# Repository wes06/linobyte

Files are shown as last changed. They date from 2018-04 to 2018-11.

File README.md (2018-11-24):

# LINOBYTE

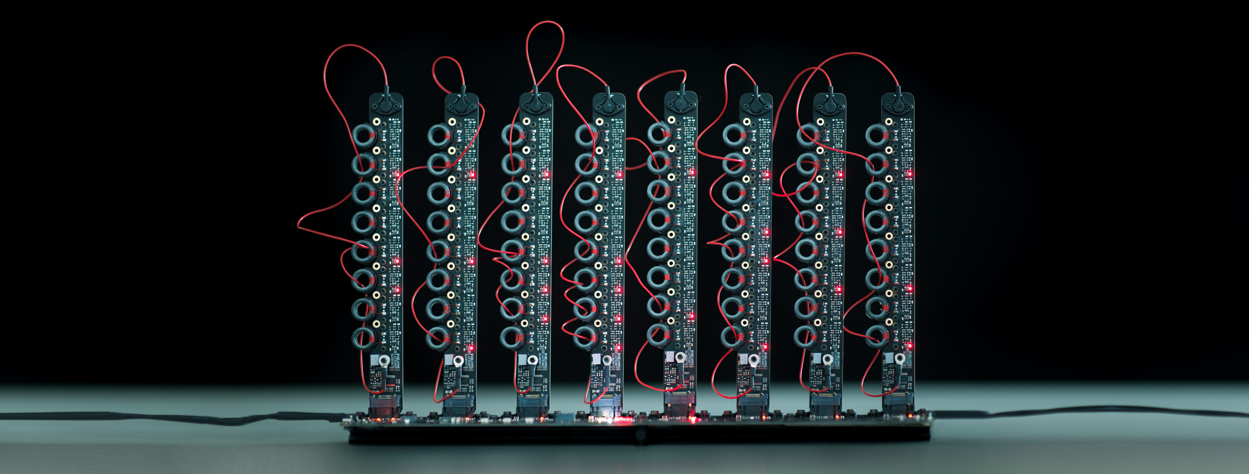
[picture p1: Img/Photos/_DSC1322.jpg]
Linobyte


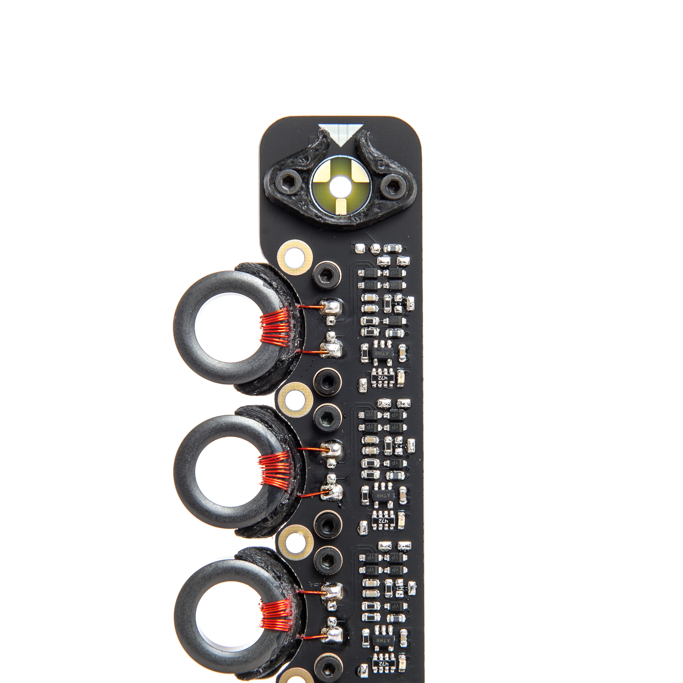
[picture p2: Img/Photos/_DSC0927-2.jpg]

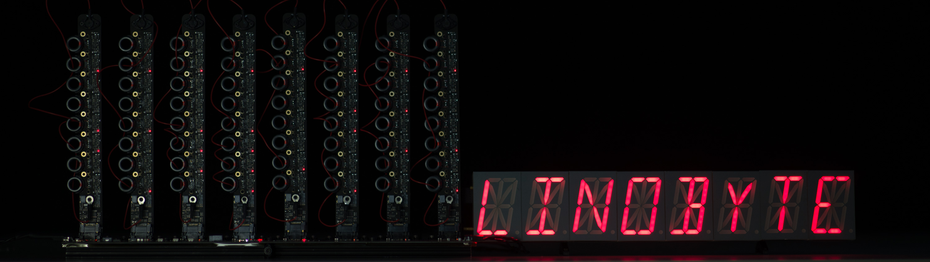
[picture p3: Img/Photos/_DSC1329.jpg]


## Table of Contents

* [Motivation and Description](#motivation-description)
* [How it works](#how-it-works)
* [Important Dates](#dates)
* [Functional Block Diagram](#block-diagram)
* [Simulations](#simulations)
* [PCBs](#pcbs)
* [Naming](#naming)
* [To Dos](#to-dos)
* [Glossary](#glossary)

## Motivation and Description

As computational devices evolve, more tools and interfaces are built between the user and the machine. This allows us to complete increasingly complex tasks without having to focus so much on understanding the nuances of the machine. While this movement is certainly overall positive, one of the drawbacks is that people no longer learn the fundamental processes and concepts which allow the tool to work. Added to that, by neglecting history, we forget the alternatives of the technologies that we use today - forgotten alternatives that maybe once were the status quo. Understanding of those alternatives would give us a broader view of the pros and cons of what we have today, how they superseded their ancestors and what are their pitfalls - important knowledge for those who design possible futures.

Its with these preocupations in mind that Linobyte came into existence. It conciliates the explanation of how bits, bytes and [chars](https://en.wikipedia.org/wiki/Character_(computing)) work, with a hands on experience of creating [Core Rope ROMs](https://en.wikipedia.org/wiki/Core_rope_memory): read-only memories that were written by weaving an enameled copper wire through ferrite cores. 

## How it works

The whole process is quite straightforward, and the result is immediate: the user can write up to 8 characters - a word, in the Linobyte system. Each character consists of one eight-bit byte. Each core represents one bit, and by weaving the conductive wire through the core center, the user sets a bit as positive. By skipping the core, its set as zero. By connecting the wire to the final position, the byte is written.  

So, if the user wants to write the "A" character, the steps should be the following:

1. Find out the binary value in ASCII of the "A" character by checking on the ASCII table (see image below). "A" in ASCII is 65 in decimal and 01000001 in binary.
2. Figure out which bits have to be set in the "Char" board: the first bit (least significant), or bit 0. And the seventh bit, bit 6. (bits are being counted from the right to left)
3. Weave a wire through the respective coils: zero and six.
4. Connect the wire to the final position (will be indicated on the board)
5. Check the character on a screen and correct or proceed to the next character.

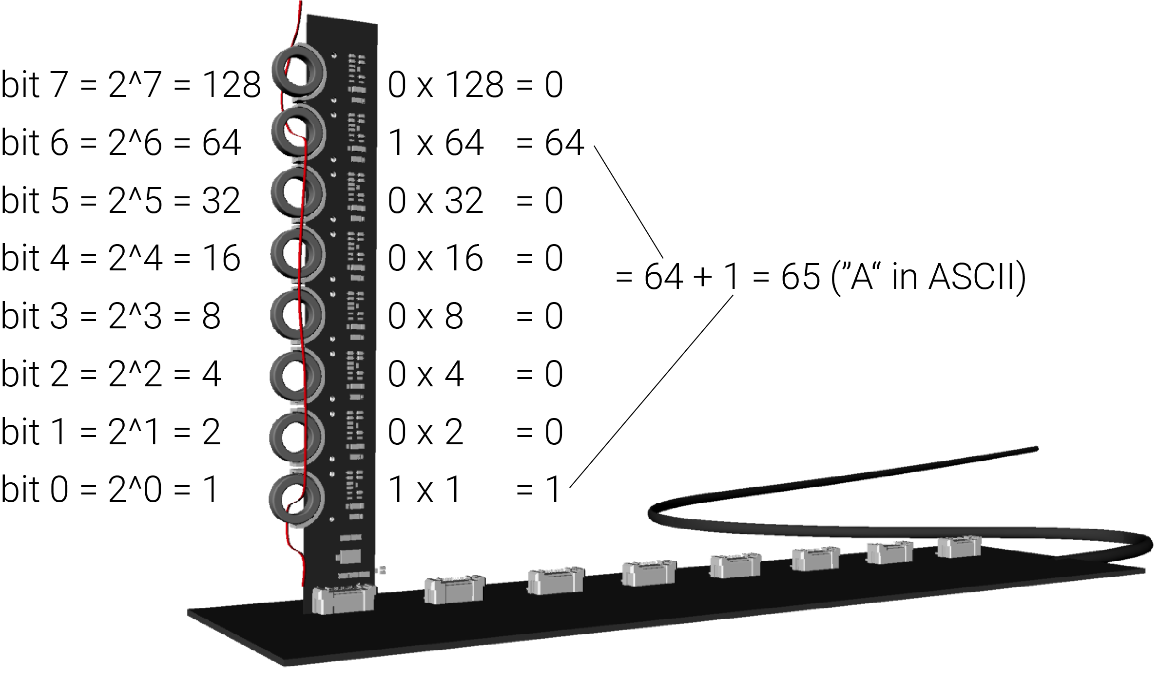
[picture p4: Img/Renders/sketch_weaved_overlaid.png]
A example
 

ASCII table:  
(I'm aware that ASCII chars only require 7 bits and not 8)



Core memory experiment from http://www.timui.org/2015/



## Functional Block Diagram

Coils are out of order in the following diagram:

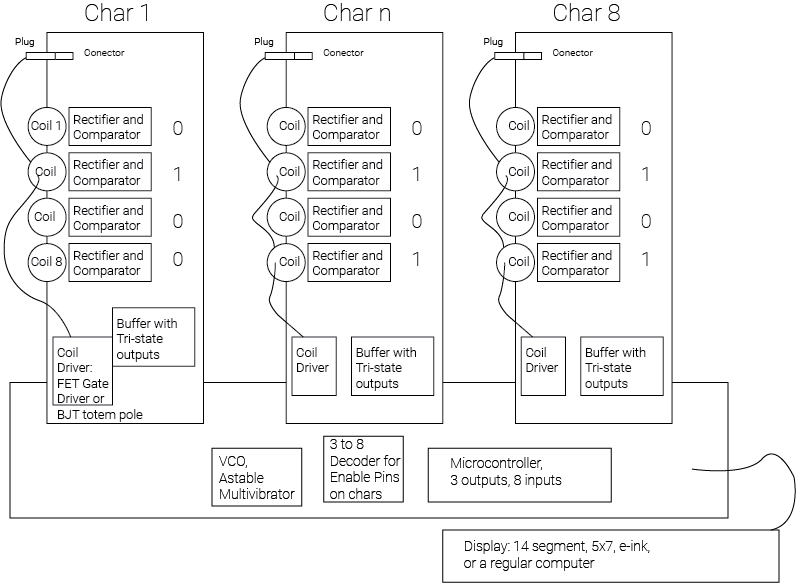
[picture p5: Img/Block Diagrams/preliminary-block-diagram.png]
Preliminary Functional Block Diagram


(So, basically, 1 word = 8 chars = 8 bytes = 8 * 8 bits)

#### Description of the main components:

##### Char

- Coil: a 1:10 to 1:30 transformer (the single turn will be the wire than can be weaved or not)
- Rectifier: Full bridge of schottky rectifiers: wire can be weaved from any direction
- Comparator: Since I don't know for sure how efficient the coil transformer will be, I want to be able to set the threshold manually.
- Coil Driver: Sends pulses through the coils. A pulse rated capacitor (probably Wima MKT) will be used in series to prevent coil saturation. Square wave signal will come from main board (either a VCO, astable multivibrator or a PWM signal from the MCU).
- Buffer with tri-state outputs: Outputs will be active or high-impedance depending on Enable pin. So I can read all chars using the same pins on the MCU.

##### Word

- VCO/Astable Multivibrator: generate a reference frequency for the coil drives. Configurable via a trimpot. Fallback will be a PWM generated by the MCU.
- 3 to 8 Decoder: with three pins on the MCU I can enable one of the 8 chars at a time, so only one of them is driving the 8 inputs on the MCU.
- Microcontroller: will read the chars and print them out.

##### Display

I personally really wanted to experiment with e-ink displays (Should be doable by adding an SPI header on the main board), but 16 segment displays or 5x7 matrixes might be more thematically suited - and are quite easy to use. Another option would be having the whole system just act as a keyboard: plug it into a computer and type the text that is in the coils (Raspberry pi + a small display for example).

##### Power supplies (not drawn)

Microcontrollers and ICs in general will use 3.3V. I might want to power the coil drivers with 5V, 12V or 24V depending on how efficient the transformers are. I plan to power the whole thing via a USB port and have the appropriate buck and boost converters on the board. I will avoid LDOs because due to the clamp diodes to 3.3V or 5V on the rectifiers, the regulator will probably need to sink some current.

## Simulations

As I designed it away from my workbench, I had to simulate some parts instead of prototyping it.

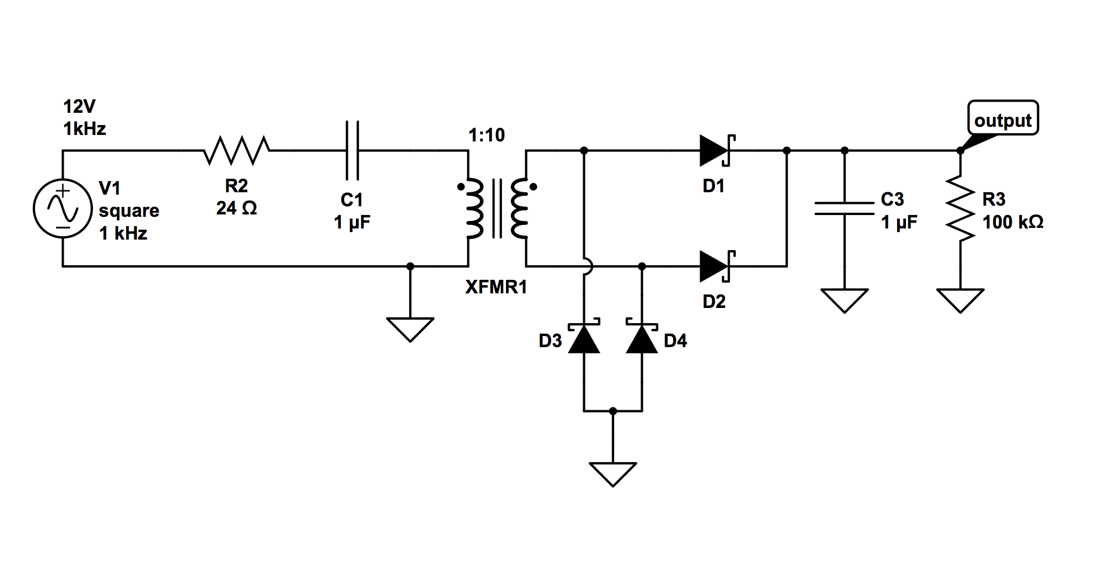
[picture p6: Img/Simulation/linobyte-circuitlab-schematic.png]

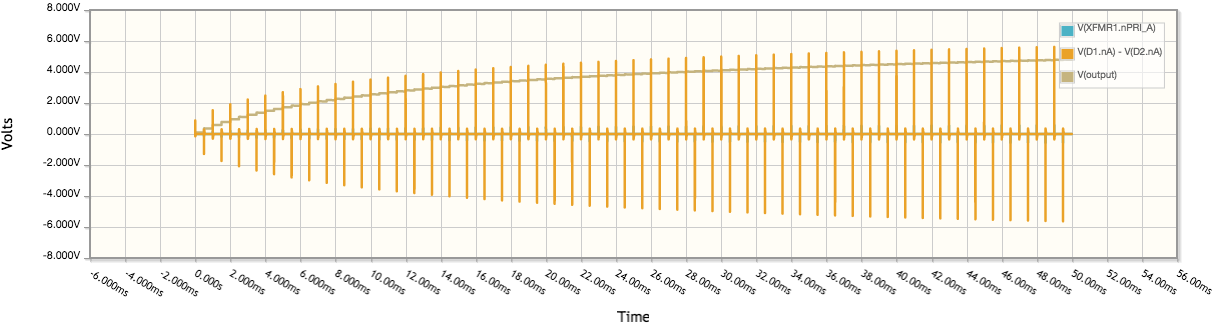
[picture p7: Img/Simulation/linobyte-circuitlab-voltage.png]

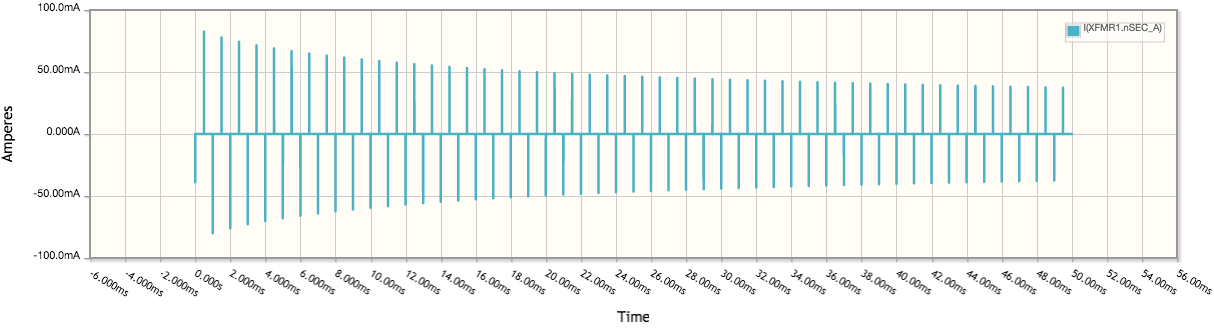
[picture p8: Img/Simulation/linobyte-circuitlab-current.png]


## PCBs

As of 19/April.  

2D view:  

  

3D view:  
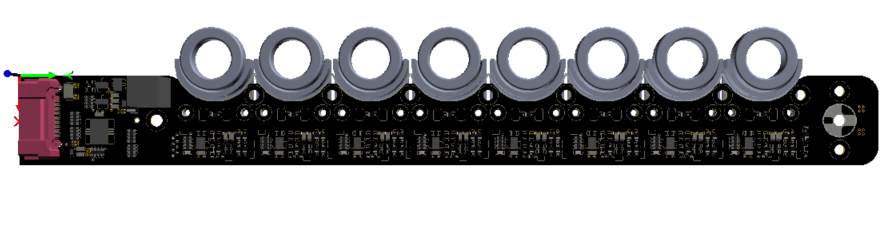
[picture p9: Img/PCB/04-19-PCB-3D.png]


As of 10/April.  

2D view:  

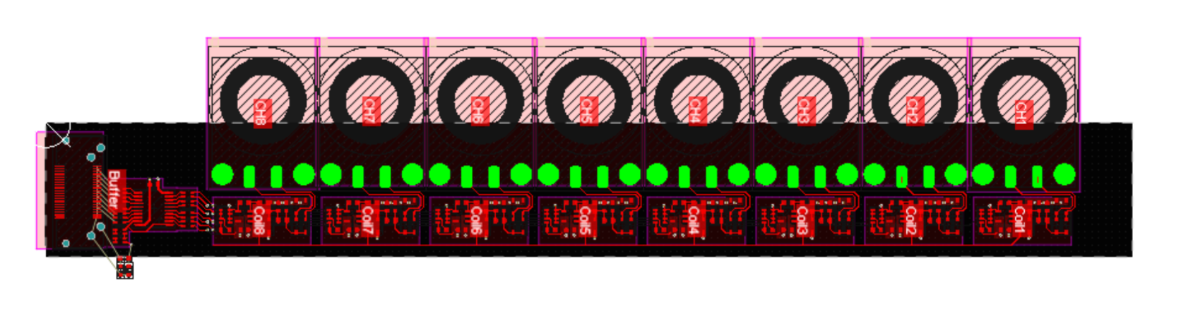
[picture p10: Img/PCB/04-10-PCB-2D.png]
  

3D view:  
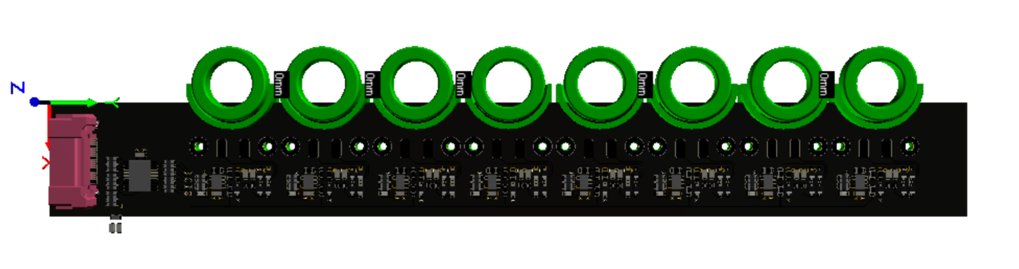
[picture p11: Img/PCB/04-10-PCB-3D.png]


## Naming

The name is a pun with the term linotype and byte:

"Linotype, typesetting machine by which characters are cast in type metal as a complete line rather than as individual characters as on the Monotype typesetting machine."

[Encyclopaedia Britannica on "Linotype"](https://www.britannica.com/technology/Linotype)  

## Refs during research

Hartmann, R. (n.d.). drhart - Core Rope Memory. [online] Drhart.ucoz.com. Available at: http://drhart.ucoz.com/index/core_memory/0-123 [Accessed Apr. 2018].

http://qrp.gr. (n.d.). Core rope memory. [online] Available at: http://qrp.gr/coreROM/ [Accessed Apr. 2018].

Ritter, T. (2002). A Magnetic Core ROM. [online] Ciphersbyritter.com. Available at: http://www.ciphersbyritter.com/MARK8/MAGCORE/MAGCORE.HTM [Accessed Apr. 2018].)

Ryals, P. (2012). Jacquard Looms and Rod ROMs. [online] Museum of Computer Culture. Available at: http://www.computerculture.org/2012/10/jacquard-looms-and-rod-roms/ [Accessed Apr. 2018].

Schlaepfer, E. (n.d.). MOnSter 6502. [online] Monster6502.com. Available at: https://monster6502.com/ [Accessed Apr. 2018].

## Examples and references during design

Pcbway.com. (n.d.). 4-layer PCB standard stackup. [online] Available at: https://www.pcbway.com/multi-layer-laminated-structure.html [Accessed May 2018].

Eeweb.com. (n.d.) Edge Coupled Microstrip Impedance Calculator. [online] Available at: https://www.eeweb.com/tools/edge-coupled-microstrip-impedance [Accessed May 2018, Tw=0.25mm Ts=0.25mm]

GitHub. (2017). dmadison/LED-Segment-ASCII. [online] Available at: https://github.com/dmadison/LED-Segment-ASCII [Accessed 10 Sep. 2018].

[Could Sawtooth waveform be optimal for transoformer input?](https://electronics.stackexchange.com/a/221279/61257)

[How to build a low cost current transformer](https://electronics.stackexchange.com/questions/116195/how-to-build-very-low-cost-current-transformer)

[AC current sensing using current transformer](https://electronics.stackexchange.com/questions/335570/ac-current-sensing-switch-using-current-transformer)

[How do I design a current transformer](https://electronics.stackexchange.com/questions/136086/how-do-i-design-a-current-transformer)

Maxim App note 3616, Adding extra histeresis to comparators  
https://www.maximintegrated.com/en/app-notes/index.mvp/id/3616

Texas Instruments: Comparator with histeresis reference design  
http://www.ti.com/lit/ug/tidu020a/tidu020a.pdf

## Potential Items for Bill of Materials

Potential coils: 9mm x 16mm x 5mm (inner, outer, thickness)  
[Mouser](https://www2.mouser.com/Passive-Components/Ferrites/Ferrite-Toroids-Ferrite-Rings/_/N-fb8t7Z1yzvvqx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|1)

Kemet ESD - R Series

[S]chmitt Trigger Octal Non Inverting](https://www.mouser.at/ProductDetail/Nexperia/74HC7541PW118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)

[3 to 8 decoder, 74HC138](https://www.mouser.at/datasheet/2/302/74HC_HCT138-1148685.pdf)

8 to 3 encoder (Auto adressing on 16 Segment Displays (shift decoded 1:8 by 1, adds 1 to 3 bit value))

Card edge 20 Pos connector  
https://www.digikey.com/product-detail/en/te-connectivity-amp-connectors/5-5530843-0/A31722-ND/770548

e-ink  
296x128 2.9in  
https://www.amazon.de/Waveshare-Resolution-Electronic-Controller-interface/dp/B071LGVVL1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

PSA23-11SRWA  (~ 300mA per char)
https://www.mouser.at/ProductDetail/Kingbright/PSA23-11SRWA?qs=VdjlWU%2fzoOGQsM3wN0NEHg==

ZXGD3005
ZXGD3009

## Glossary

- **ASCII table**: A table of correspondece between a numeric value and a character (American Standard Code for Information Interchange)

- Bit
- Byte
- Char
- **Core**: in this context, the toroid (donut) which is one of the components of the transformer that sets the bits

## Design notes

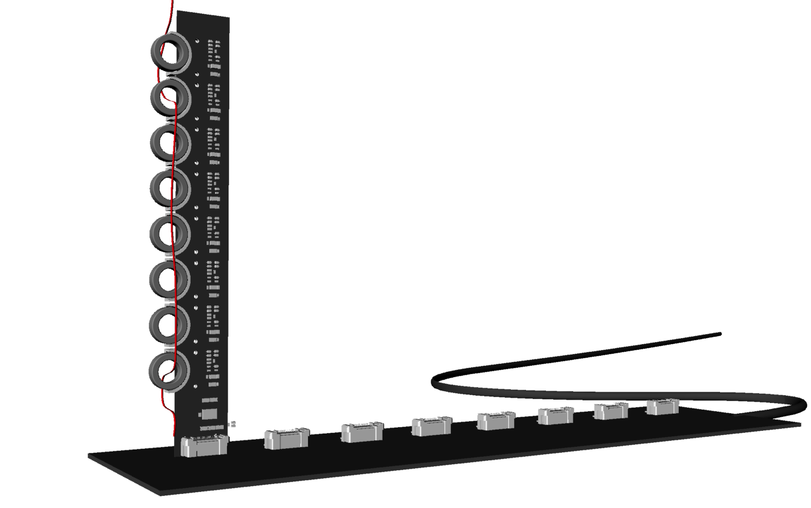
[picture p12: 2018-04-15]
Img/Renders/sketch_weaved.png

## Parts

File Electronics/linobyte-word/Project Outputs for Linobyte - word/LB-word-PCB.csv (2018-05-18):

Comment | Description | Designator | Footprint | LibRef | Quantity
100nF | Capacitor MLCC | C1, C2_Char1, C2_Char2, C2_Char3, C2_Char4, C2_Char5, C2_Char6, C2_Char7, C2_Char8, C3_Char1, C3_Char2, C3_Char3, C3_Char4, C3_Char5, C3_Char6, C3_Char7, C3_Char8, C5_Char1, C5_Char2, C5_Char3, C5_Char4, C5_Char5, C5_Char6, C5_Char7, C5_Char8, C6_Char1, C6_Char2, C6_Char3, C6_Char4, C6_Char5, C6_Char6, C6_Char7, C6_Char8, C7_Char1, C7_Char2, C7_Char3, C7_Char4, C7_Char5, C7_Char6, C7_Char7, C7_Char8, C8_Char1, C8_Char2, C8_Char3, C8_Char4, C8_Char5, C8_Char6, C8_Char7, C8_Char8, C9, C10, C11, C13, C14, C15, C16, C18, C19, C20, C21, C23, C24, C25, C26, C27, C31, C33, C34, C35, C38_Char1, C38_Char2, C38_Char3, C38_Char4, C38_Char5, C38_Char6, C38_Char7, C38_Char8, CBST1, CR1 | C0603_N | Capacitor | 79
Test Point |  | TP_COMP1, TP_LOOP1, TP_OUT1, TP_SCL, TP_SCL1, TP_SDA, TP_SDA1, TP_SHUNT1, TP_SW1, TP_VIN1, TP1_Char1, TP1_Char2, TP1_Char3, TP1_Char4, TP1_Char5, TP1_Char6, TP1_Char7, TP1_Char8, TP2_Char1, TP2_Char2, TP2_Char3, TP2_Char4, TP2_Char5, TP2_Char6, TP2_Char7, TP2_Char8, TP3, TP4, TP5, TP6, TP7, TP8, TP9, TP10, TP11, TP12, TP13, TP14, TP15, TP16, TP17, TP18, TP19, TP20, TP21, TP22, TP23, TP24, TP25 | TESTPOINT-1.2MM | Test Point | 49
LED | LED | L1, L2, L3, L4, L5, L6, L7, L8, L9, L10, L11, L12, L13, L14, L15, L16, L17, L18, L19, L20, L21, L22, L25_Char1, L25_Char2, L25_Char3, L25_Char4, L25_Char5, L25_Char6, L25_Char7, L25_Char8 | LED 0603/1608 | LED | 30
10k |  | R7_Char1, R7_Char2, R7_Char3, R7_Char4, R7_Char5, R7_Char6, R7_Char7, R7_Char8, R8_Char1, R8_Char2, R8_Char3, R8_Char4, R8_Char5, R8_Char6, R8_Char7, R8_Char8, R13, R22, R23, R24_Char1, R24_Char2, R24_Char3, R24_Char4, R24_Char5, R24_Char6, R24_Char7, R24_Char8, R27, R34 | R0603 | Resistor | 29
FB |  | FB1_Char1, FB1_Char2, FB1_Char3, FB1_Char4, FB1_Char5, FB1_Char6, FB1_Char7, FB1_Char8, FB2_Char1, FB2_Char2, FB2_Char3, FB2_Char4, FB2_Char5, FB2_Char6, FB2_Char7, FB2_Char8, FB3_Char1, FB3_Char2, FB3_Char3, FB3_Char4, FB3_Char5, FB3_Char6, FB3_Char7, FB3_Char8, FBA1 | F0603_N | Ferrite Bead | 25
SIA483DJ-T1-GE3 |  | Q1_Char1, Q1_Char2, Q1_Char3, Q1_Char4, Q1_Char5, Q1_Char6, Q1_Char7, Q1_Char8, Q2_Char1, Q2_Char2, Q2_Char3, Q2_Char4, Q2_Char5, Q2_Char6, Q2_Char7, Q2_Char8, Q4, Q5 | SC70-6L | MOSFET P CH | 18
 |  | Hole1_Char1, Hole1_Char2, Hole1_Char3, Hole1_Char4, Hole1_Char5, Hole1_Char6, Hole1_Char7, Hole1_Char8, Hole2_Char1, Hole2_Char2, Hole2_Char3, Hole2_Char4, Hole2_Char5, Hole2_Char6, Hole2_Char7, Hole2_Char8 | M3 PLATED HOLE | Hole | 16
10uF 50V | Capacitor MLCC | C4_Char1, C4_Char2, C4_Char3, C4_Char4, C4_Char5, C4_Char6, C4_Char7, C4_Char8, C28, C29, C36, C37, CI1, CI2, CI3 | C1210_N | Capacitor | 15
YC164; 1k |  | R1, R2, R3, R4, R5, R6, R11, R12, R26, R28, R29, R41 | YC164 | Resistor Array - 4P | 12
=Footprint |  | Hole3, Hole4, Hole5, Hole6, Hole7, Hole8, Hole9, Hole10, Hole11, Hole12, Hole13 | M3 PLATED HOLE | Hole | 11
Jumper 3W |  | JP1, JP3, JP11_Char1, JP11_Char2, JP11_Char3, JP11_Char4, JP11_Char5, JP11_Char6, JP11_Char7, JP11_Char8 | JUMPER SMD 3W NO | Jumper 3W | 10
74LVC1G125 | Buffer with Enable | U11_Char1, U11_Char2, U11_Char3, U11_Char4, U11_Char5, U11_Char6, U11_Char7, U11_Char8 | SC70-5 | 74LVC1G125 | 8
FX23 Vertical Plug | FX23 Vertical Plug | X1_Char1, X1_Char2, X1_Char3, X1_Char4, X1_Char5, X1_Char6, X1_Char7, X1_Char8 | FX23-40P | FX23-40P | 8
Jumper 2W |  | JP2, JP4, JP5, JP6, JP7, JP8, JP9, JP10 | JUMPER SMD 2W NO | Jumper 2W | 8
PTC | PTC, Resettable Fuse | F2_Char1, F2_Char2, F2_Char3, F2_Char4, F2_Char5, F2_Char6, F2_Char7, F2_Char8 | PTC0603 | PTC | 8
PTC1206 | PTC, Resettable Fuse | F1_Char1, F1_Char2, F1_Char3, F1_Char4, F1_Char5, F1_Char6, F1_Char7, F1_Char8 | C1206_N | PTC | 8
120R |  | R16, R20, R36, R39 | R0603 | Resistor | 4
600 |  | R35, R37, R38, R40 | R0603 | Resistor | 4
YC164; 100k |  | R15, R17, R18, R21 | YC164 | Resistor Array - 4P | 4
100pF | Capacitor MLCC | C17, C22, C32 | C0603_N | Capacitor | 3
1k |  | R9, R10, R19 | R0603 | Resistor | 3
PTC | PTC, Resettable Fuse | F3, F4, F5 | 1812 | PTC | 3
TLV171 | Single RRO Opamp | U4, U5, U6 | SOT23-5_N | TLV171 | 3
Trimpot |  | VR1, VR2, VR3 | TRIMPOT 3314 | Trimpot | 3
0R5 |  | SHUNT1, SHUNT2 | R0603 | Resistor | 2
22pF | Capacitor MLCC | CX1, CX2 | C0603_N | Capacitor | 2
22uF 10V | Capacitor MLCC | CO1, CO2 | C1210_N | Capacitor | 2
Connector 2W - TAB |  | X2, X6 | PTSM-2W-H-SMD | Connector 2W - TAB | 2
MCP23008 | I2C Port Expander | U7, U8 | QFN20 | MCP23008 | 2
RsI2C |  | RS_SCL1, RS_SDA1 | R0603 | Resistor | 2
RSX051VYM30FHTR |  | D3, D4 | SOD323F | Diode Schottky | 2
YC164; 1M |  | R42, R43 | YC164 | Resistor Array - 4P | 2
100k |  | RFB1 | R0603 | Resistor | 1
112k |  | R31 | R0603 | Resistor | 1
1778803 |  | X7 | PTSM-6W-H-SMD | Connector 6W - TAB | 1
1uF | Capacitor MLCC | C12 | C0603_N | Capacitor | 1
20021521-00010T1LF |  | SWD1 | HEADER 10P 50MIL | SWD | 1
22k |  | RFB2 | R0603 | Resistor | 1
2k5 |  | R33 | R0603 | Resistor | 1
330R |  | R14 | R0603 | Resistor | 1
50R |  | R30 | R0603 | Resistor | 1
74HC138 | 3 to 8 Decoder | U1 | DHVQFN16 | 74HC138 | 1
74HC7541 | Schmitt Trigger Octal | U2 | TSSOP20_N | 74HC7541 | 1
78k7 |  | R32 | R0603 | Resistor | 1
824521121 |  | D7 | SOD323F | TVS | 1
824521121 |  | TVS1 | DO214AC SMA | TVS Bidirectional | 1
ATSAMD21G18 |  | U3 | QFN48_M | ATSAMD21G18 | 1
CFF | Capacitor MLCC | CFF1 | C0603_N | Capacitor | 1
Connector 10W - TAB |  | X5 | FPC CONN. 10W 1-84953-0 | Connector 10W - TAB | 1
Ferrite Bead |  | FB4 | F0603_N | Ferrite Bead | 1
Header 14Pos 7x2 |  | X4 | HEADER 7X2 SMD 2.54MM | Header 14Pos 7x2 | 1
Inductor |  | L24 | INDUCTOR SRP1040 | Inductor | 1
LFXTAL050789 |  | X3 | CRYSTAL 0805 | Crystal | 1
MM3Z3V3ST1G |  | D1 |  | TVS | 1
MM3Z3V3ST1G |  | D5 | SOD323F-COMCHIP VARIANT | TVS | 1
MOSFET N CH |  | Q3 | SOT23_N | MOSFET N CH | 1
PCA9615 |  | U10 | TSSOP10 | PCA9615DP | 1
SBR5E60P5-13D |  | D6 | POWERDI5 | Diode Schottky | 1
SRP7028 |  | L23 | INDUCTOR SRP7028 | Inductor | 1
T55D336M035C0100 | Polarized Cap | C30 | 2917 - CASE D | Capacitor Polarized | 1
TPD3E001 |  | TVS2 | SOT23-5_N | TPD3E001 | 1
TPS54308 | Buck Converter | IC1 | SOT23 | TPS54308 | 1
TPS55340 | Boost/SEPIC/Flyback converter | U9 | QFN16 | TPS55340 | 1
USB Micro |  | USB1 | USB MICRO | USB Micro | 1
YC164; 10k |  | R25 | YC164 | Resistor Array - 4P | 1
YC164; 4k7 |  | RI1 | YC164 | Resistor Array - 4P | 1

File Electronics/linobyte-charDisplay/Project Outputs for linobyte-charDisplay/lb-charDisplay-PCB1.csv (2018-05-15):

Comment | Value | Description | Designator | Footprint | LibRef | Quantity
 |  |  | RFB1A | R0603 | Resistor | 1
0R5 | 0R5 |  | SHUNT1 | R0603 | Resistor | 1
10uF 50V | 10uF 50V | Capacitor MLCC | CI1 | C1210_N | Capacitor | 1
16 Segment Display |  |  | DISP1 | PSA23-11SRWA | Display 16 Segment | 1
22k | 22k |  | RFB2 | R0603 | Resistor | 1
22uF 10V | 22uF 10V | Capacitor MLCC | CO1 | C1210_N | Capacitor | 1
100k | 100k |  | RFB1B | R0603 | Resistor | 1
100nF | 100nF | Capacitor MLCC | C1, C2, C3, C4, C5, C6, C7, C8, CBST1 | C0603_N | Capacitor | 9
120 | 120 |  | R4, R7 | R0603 | Resistor | 2
600 | 600 |  | R3, R5, R6, R8 | R0603 | Resistor | 4
1778803 |  |  | X3 | PTSM-6W-H-SMD | Connector 6W - TAB | 1
; 4k7 | 4k7 |  | R1, R2 | YC164 | Resistor Array - 4P | 2
=Footprint |  |  | Hole1, Hole2, Hole3, Hole4 | Insert-Thread-SMD-M2 | Hole | 4
Connector 10W - TAB |  |  | X1, X2 | FPC Conn. 10W 1-84953-0 | Connector 10W - TAB | 2
HVQFN28 |  |  | U3 | QFN28 | PCA9685 | 1
Inductor | 15uH |  | L1 | Inductor 4mm | Inductor | 1
Jumper 2W |  |  | JP_A0, JP_A1, JP_A2, JP_A3, JP_A4, JP_A5, JP1, JP2, JP3 | Jumper SMD 2W NO | Jumper 2W | 9
Jumper 3W |  |  | JP4, JP5 | Jumper SMD 3W NO | Jumper 3W | 2
PCA9615 |  |  | U1 | TSSOP10 | PCA9615DP | 1
Resistor Array - 4P |  |  | R17, R18, R20, R21 | YC164 | Resistor Array - 4P | 4
Test Point |  |  | TP1, TP2, TP3, TP4, TP5, TP6 | TestPoint-1.2mm | Test Point | 6
TPS54308 |  | Buck Converter | IC1 | SOT23 | TPS54308 | 1
TPS70933 |  |  | U2 | SOT23-5_N | XC6222 | 1

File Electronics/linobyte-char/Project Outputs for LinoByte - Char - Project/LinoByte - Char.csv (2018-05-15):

Comment | Description | Designator | Footprint | LibRef | Quantity
Silkscreen Digit |  | 1_CH1, 1_CH2, 1_CH3, 1_CH4, 1_CH5, 1_CH6, 1_CH7, 1_CH8 | PCB-7SEG-10MM | PCB-7Seg | 8
100nF | Capacitor MLCC | C1_Coil1, C1_Coil2, C1_Coil3, C1_Coil4, C1_Coil5, C1_Coil6, C1_Coil7, C1_Coil8, C2_Coil1, C2_Coil2, C2_Coil3, C2_Coil4, C2_Coil5, C2_Coil6, C2_Coil7, C2_Coil8, C3, C4, C4_Coil1, C4_Coil2, C4_Coil3, C4_Coil4, C4_Coil5, C4_Coil6, C4_Coil7, C4_Coil8, C5, C7, C10 | C0603_N | Capacitor | 29
Film |  | C6 | CAP FILM 5MM PITCH, 7.2X7.2MM | Capacitor - Film | 1
1206 10uF 25V | Capacitor MLCC | C8 | C1206_N | Capacitor | 1
1uF | Capacitor MLCC | C9 | C0603_N | Capacitor | 1
DNP | Capacitor MLCC | C11 | C0603_N | Capacitor | 1
RSX051VYM30FHTR |  | D1, D2, D4, DClamp_Coil1, DClamp_Coil2, DClamp_Coil3, DClamp_Coil4, DClamp_Coil5, DClamp_Coil6, DClamp_Coil7, DClamp_Coil8, DR1_Coil1, DR1_Coil2, DR1_Coil3, DR1_Coil4, DR1_Coil5, DR1_Coil6, DR1_Coil7, DR1_Coil8, DR2_Coil1, DR2_Coil2, DR2_Coil3, DR2_Coil4, DR2_Coil5, DR2_Coil6, DR2_Coil7, DR2_Coil8, DR3_Coil1, DR3_Coil2, DR3_Coil3, DR3_Coil4, DR3_Coil5, DR3_Coil6, DR3_Coil7, DR3_Coil8, DR4_Coil1, DR4_Coil2, DR4_Coil3, DR4_Coil4, DR4_Coil5, DR4_Coil6, DR4_Coil7, DR4_Coil8 | SOD323F | Diode, Diode Schottky | 43
TVS |  | D3 |  | TVS | 1
FB |  | FB1_Coil1, FB1_Coil2, FB1_Coil3, FB1_Coil4, FB1_Coil5, FB1_Coil6, FB1_Coil7, FB1_Coil8 | R0603 | Resistor | 8
Ferrite Bead |  | FB2 | F0603_N | Ferrite Bead | 1
FB |  | FB3 | F0603_N | Ferrite Bead | 1
Hole |  | Hole1 | INSERT-THREAD-SMD-M2 | Hole | 1
linobyte-coil |  | L1_CH1, L1_CH2, L1_CH3, L1_CH4, L1_CH5, L1_CH6, L1_CH7, L1_CH8 | LINOBYTE-COIL | linobyte-coil | 8
LED | LED | L1_Coil1, L1_Coil2, L1_Coil3, L1_Coil4, L1_Coil5, L1_Coil6, L1_Coil7, L1_Coil8 | LED 0603/1608 | LED | 8
MOSFET N CH |  | Q1, Q2 | SOT23_N | MOSFET N CH | 2
120R |  | R1_Coil1, R1_Coil2, R1_Coil3, R1_Coil4, R1_Coil5, R1_Coil6, R1_Coil7, R1_Coil8, R12 | R0603 | Resistor | 9
; 1k |  | R2, R4, R5, R6, R7 | YC164 | Resistor Array - 4P | 5
1M |  | R3_Coil1, R3_Coil2, R3_Coil3, R3_Coil4, R3_Coil5, R3_Coil6, R3_Coil7, R3_Coil8 | R0603 | Resistor | 8
DNP |  | R4_Coil1, R4_Coil2, R4_Coil3, R4_Coil4, R4_Coil5, R4_Coil6, R4_Coil7, R4_Coil8 | R0603 | Resistor | 8
YC164; 1k |  | R8_Coil1, R8_Coil2, R8_Coil3, R8_Coil4, R8_Coil5, R8_Coil6, R8_Coil7, R8_Coil8, R9 | YC164 | Resistor Array - 4P | 9
1k |  | R10, R11, Rin_Coil1, Rin_Coil2, Rin_Coil3, Rin_Coil4, Rin_Coil5, Rin_Coil6, Rin_Coil7, Rin_Coil8 | R0603 | Resistor | 10
4k7 |  | Rfb_Coil1, Rfb_Coil2, Rfb_Coil3, Rfb_Coil4, Rfb_Coil5, Rfb_Coil6, Rfb_Coil7, Rfb_Coil8 | R0603 | Resistor | 8
Switch for the magnet |  | SW1 | LINOBYTE - MAGNETSWITCH | Linobyte - MagnetSwitch | 1
Test Point |  | TP1_Coil1, TP1_Coil2, TP1_Coil3, TP1_Coil4, TP1_Coil5, TP1_Coil6, TP1_Coil7, TP1_Coil8, TP2_Coil1, TP2_Coil2, TP2_Coil3, TP2_Coil4, TP2_Coil5, TP2_Coil6, TP2_Coil7, TP2_Coil8, TP3_Coil1, TP3_Coil2, TP3_Coil3, TP3_Coil4, TP3_Coil5, TP3_Coil6, TP3_Coil7, TP3_Coil8, TP4_Coil1, TP4_Coil2, TP4_Coil3, TP4_Coil4, TP4_Coil5, TP4_Coil6, TP4_Coil7, TP4_Coil8 | HARWIN S2751-46R | Test Point | 32
TVS Bidirectional |  | TVS1 | DO214AC SMA | TVS Bidirectional | 1
TVS Bidirectional |  | TVS2_Coil1, TVS2_Coil2, TVS2_Coil3, TVS2_Coil4, TVS2_Coil5, TVS2_Coil6, TVS2_Coil7, TVS2_Coil8 |  | TVS Bidirectional | 8
74HC7541 | Schmitt Trigger Octal | U1 | TSSOP20_N | 74HC7541 | 1
ZXGD3005 |  | U2 | SOT23-6_N | ZXGD3005 | 1
MCP6541U |  | U3_Coil1, U3_Coil2, U3_Coil3, U3_Coil4, U3_Coil5, U3_Coil6, U3_Coil7, U3_Coil8 | SOT23-5_N | MCP6541U | 8
FX23 Right Angle Receptacle | FX23 Right Angle Receptacle 40 Pos | X1 | FX23-40S-0.5SH | FX23-40S-0.5SH | 1

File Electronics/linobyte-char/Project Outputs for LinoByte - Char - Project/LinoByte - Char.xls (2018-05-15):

Comment | Description | Designator | Footprint | LibRef | Quantity
Silkscreen Digit |  | 1_CH1, 1_CH2, 1_CH3, 1_CH4, 1_CH5, 1_CH6, 1_CH7, 1_CH8 | PCB-7SEG-10MM | PCB-7Seg | 8.0
100nF | Capacitor MLCC | C1_Coil1, C1_Coil2, C1_Coil3, C1_Coil4, C1_Coil5, C1_Coil6, C1_Coil7, C1_Coil8, C2_Coil1, C2_Coil2, C2_Coil3, C2_Coil4, C2_Coil5, C2_Coil6, C2_Coil7, C2_Coil8, C3, C4, C4_Coil1, C4_Coil2, C4_Coil3, C4_Coil4, C4_Coil5, C4_Coil6, C4_Coil7, C4_Coil8, C5, C7, C10 | C0603_N | Capacitor | 29.0
Film |  | C6 | CAP FILM 5MM PITCH, 7.2X7.2MM | Capacitor - Film | 1.0
1206 10uF 25V | Capacitor MLCC | C8 | C1206_N | Capacitor | 1.0
1uF | Capacitor MLCC | C9 | C0603_N | Capacitor | 1.0
DNP | Capacitor MLCC | C11 | C0603_N | Capacitor | 1.0
RSX051VYM30FHTR |  | D1, D2, D4, DClamp_Coil1, DClamp_Coil2, DClamp_Coil3, DClamp_Coil4, DClamp_Coil5, DClamp_Coil6, DClamp_Coil7, DClamp_Coil8, DR1_Coil1, DR1_Coil2, DR1_Coil3, DR1_Coil4, DR1_Coil5, DR1_Coil6, DR1_Coil7, DR1_Coil8, DR2_Coil1, DR2_Coil2, DR2_Coil3, DR2_Coil4, DR2_Coil5, DR2_Coil6, DR2_Coil7, DR2_Coil8, DR3_Coil1, DR3_Coil2, DR3_Coil3, DR3_Coil4, DR3_Coil5, DR3_Coil6, DR3_Coil7, DR3_Coil8, DR4_Coil1, DR4_Coil2, DR4_Coil3, DR4_Coil4, DR4_Coil5, DR4_Coil6, DR4_Coil7, DR4_Coil8 | SOD323F | Diode, Diode Schottky | 43.0
TVS |  | D3 |  | TVS | 1.0
FB |  | FB1_Coil1, FB1_Coil2, FB1_Coil3, FB1_Coil4, FB1_Coil5, FB1_Coil6, FB1_Coil7, FB1_Coil8 | R0603 | Resistor | 8.0
Ferrite Bead |  | FB2 | F0603_N | Ferrite Bead | 1.0
FB |  | FB3 | F0603_N | Ferrite Bead | 1.0
Hole |  | Hole1 | INSERT-THREAD-SMD-M2 | Hole | 1.0
linobyte-coil |  | L1_CH1, L1_CH2, L1_CH3, L1_CH4, L1_CH5, L1_CH6, L1_CH7, L1_CH8 | LINOBYTE-COIL | linobyte-coil | 8.0
LED | LED | L1_Coil1, L1_Coil2, L1_Coil3, L1_Coil4, L1_Coil5, L1_Coil6, L1_Coil7, L1_Coil8 | LED 0603/1608 | LED | 8.0
MOSFET N CH |  | Q1, Q2 | SOT23_N | MOSFET N CH | 2.0
120R |  | R1_Coil1, R1_Coil2, R1_Coil3, R1_Coil4, R1_Coil5, R1_Coil6, R1_Coil7, R1_Coil8, R12 | R0603 | Resistor | 9.0
; 1k |  | R2, R4, R5, R6, R7 | YC164 | Resistor Array - 4P | 5.0
1M |  | R3_Coil1, R3_Coil2, R3_Coil3, R3_Coil4, R3_Coil5, R3_Coil6, R3_Coil7, R3_Coil8 | R0603 | Resistor | 8.0
DNP |  | R4_Coil1, R4_Coil2, R4_Coil3, R4_Coil4, R4_Coil5, R4_Coil6, R4_Coil7, R4_Coil8 | R0603 | Resistor | 8.0
YC164; 1k |  | R8_Coil1, R8_Coil2, R8_Coil3, R8_Coil4, R8_Coil5, R8_Coil6, R8_Coil7, R8_Coil8, R9 | YC164 | Resistor Array - 4P | 9.0
1k |  | R10, R11, Rin_Coil1, Rin_Coil2, Rin_Coil3, Rin_Coil4, Rin_Coil5, Rin_Coil6, Rin_Coil7, Rin_Coil8 | R0603 | Resistor | 10.0
4k7 |  | Rfb_Coil1, Rfb_Coil2, Rfb_Coil3, Rfb_Coil4, Rfb_Coil5, Rfb_Coil6, Rfb_Coil7, Rfb_Coil8 | R0603 | Resistor | 8.0
Switch for the magnet |  | SW1 | LINOBYTE - MAGNETSWITCH | Linobyte - MagnetSwitch | 1.0
Test Point |  | TP1_Coil1, TP1_Coil2, TP1_Coil3, TP1_Coil4, TP1_Coil5, TP1_Coil6, TP1_Coil7, TP1_Coil8, TP2_Coil1, TP2_Coil2, TP2_Coil3, TP2_Coil4, TP2_Coil5, TP2_Coil6, TP2_Coil7, TP2_Coil8, TP3_Coil1, TP3_Coil2, TP3_Coil3, TP3_Coil4, TP3_Coil5, TP3_Coil6, TP3_Coil7, TP3_Coil8, TP4_Coil1, TP4_Coil2, TP4_Coil3, TP4_Coil4, TP4_Coil5, TP4_Coil6, TP4_Coil7, TP4_Coil8 | HARWIN S2751-46R | Test Point | 32.0
TVS Bidirectional |  | TVS1 | DO214AC SMA | TVS Bidirectional | 1.0
TVS Bidirectional |  | TVS2_Coil1, TVS2_Coil2, TVS2_Coil3, TVS2_Coil4, TVS2_Coil5, TVS2_Coil6, TVS2_Coil7, TVS2_Coil8 |  | TVS Bidirectional | 8.0
74HC7541 | Schmitt Trigger Octal | U1 | TSSOP20_N | 74HC7541 | 1.0
ZXGD3005 |  | U2 | SOT23-6_N | ZXGD3005 | 1.0
MCP6541U |  | U3_Coil1, U3_Coil2, U3_Coil3, U3_Coil4, U3_Coil5, U3_Coil6, U3_Coil7, U3_Coil8 | SOT23-5_N | MCP6541U | 8.0
FX23 Right Angle Receptacle | FX23 Right Angle Receptacle 40 Pos | X1 | FX23-40S-0.5SH | FX23-40S-0.5SH | 1.0

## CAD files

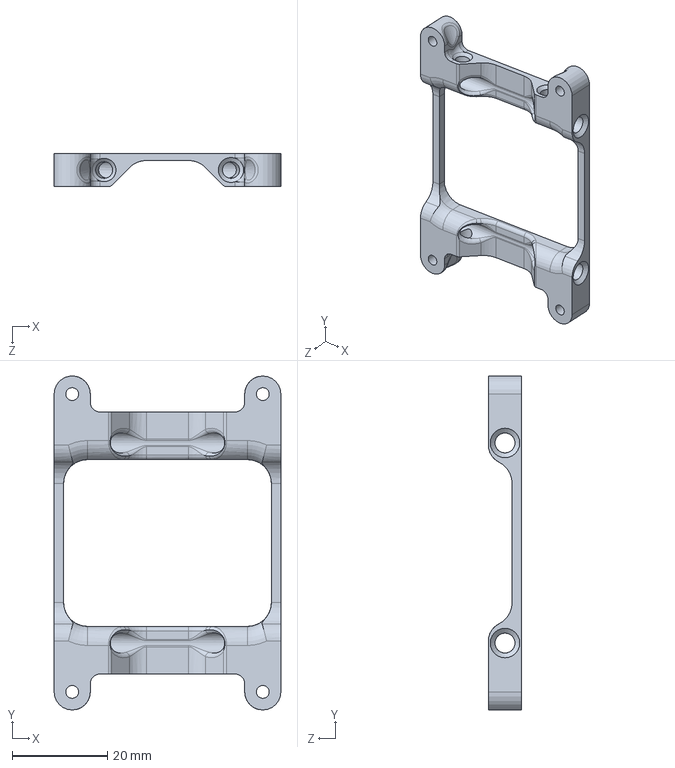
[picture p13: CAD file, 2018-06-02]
Mechanical/Char Display/LB-charDisp-Support.SLDPRT
47.6 x 70.1 x 7.00 mm

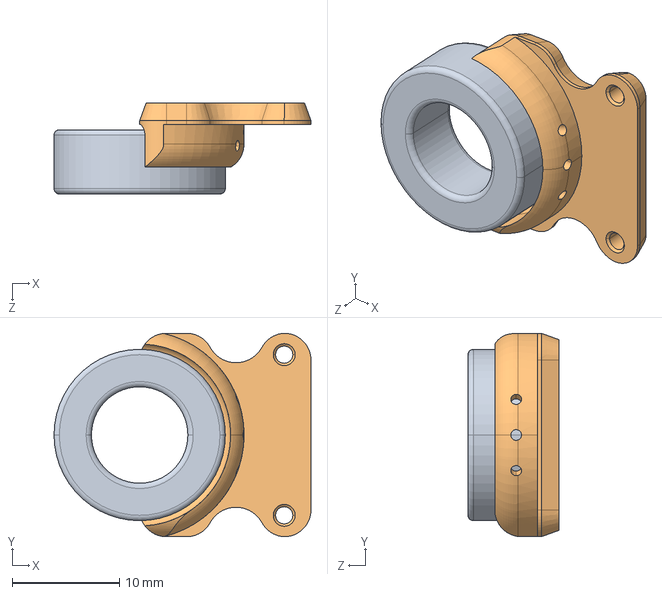
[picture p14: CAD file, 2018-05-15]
Mechanical/Chars/Coil Holders/Linobyte-CoilHolderSketch.STEP
24.0 x 19.0 x 8.50 mm

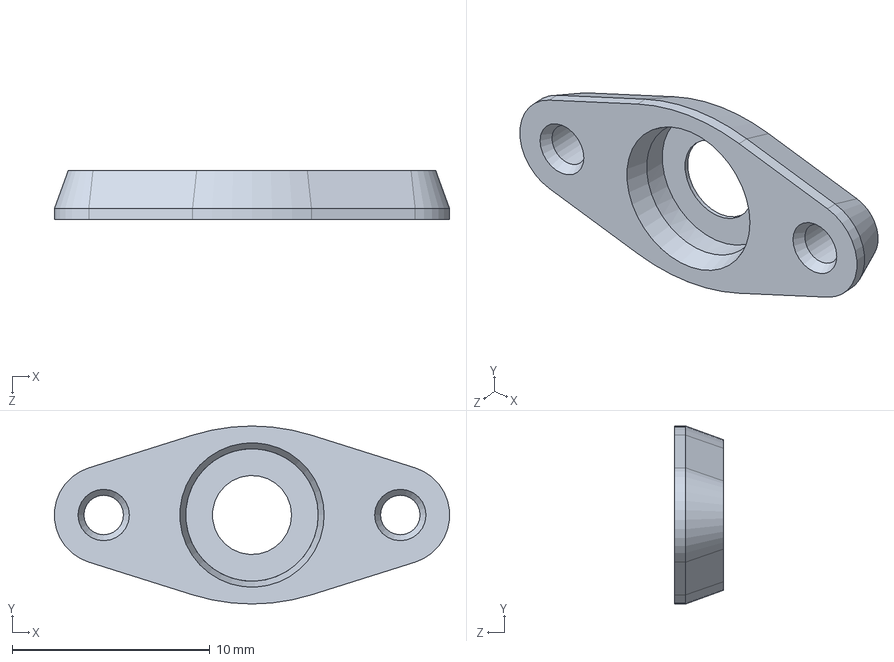
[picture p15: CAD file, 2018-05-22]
Mechanical/Chars/MagnetHolder/LB-magnetHolder-Back.SLDPRT
20.0 x 9.00 x 2.50 mm

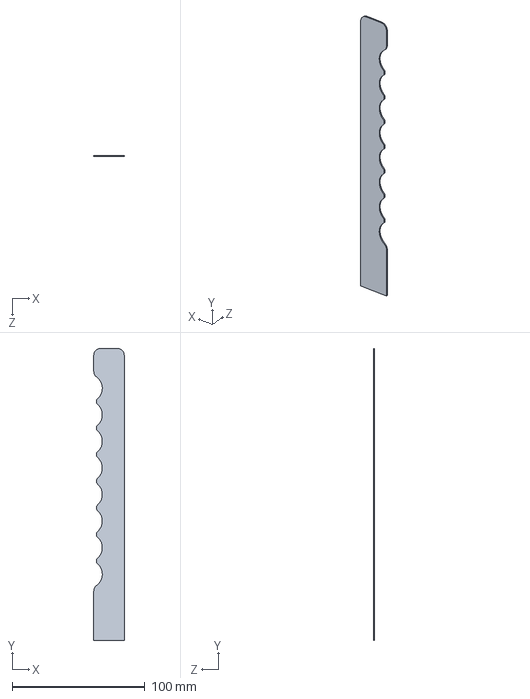
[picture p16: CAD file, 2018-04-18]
Mechanical/Chars/PCB-Shape/Linobyte - PCB Shape.SLDPRT
23.0 x 220.0 x 1.00 mm

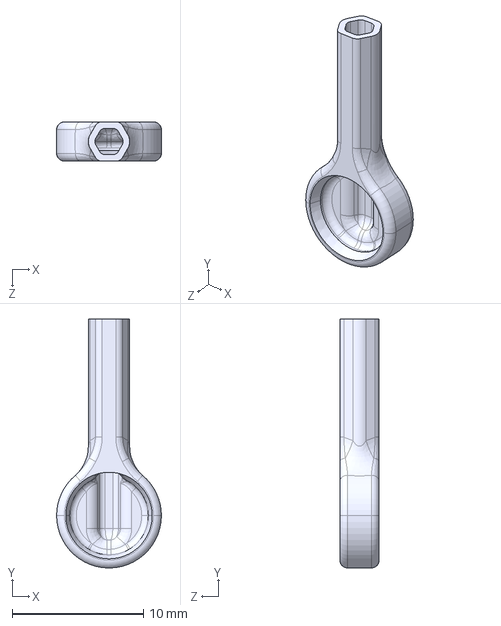
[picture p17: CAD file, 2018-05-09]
Mechanical/Chars/WireMagnetClamp/WireMagnetClamp.STEP
8.00 x 19.0 x 3.00 mm

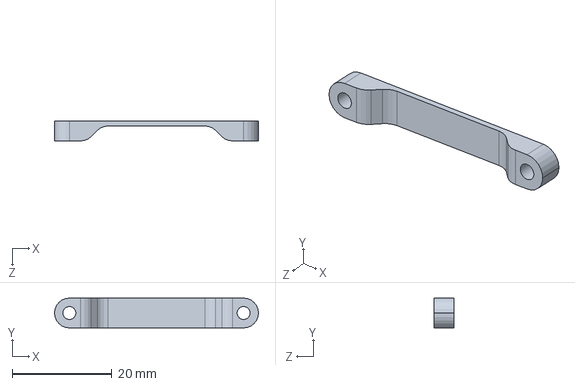
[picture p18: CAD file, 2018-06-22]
Mechanical/Word/LB-Word-charGuide-bottom.SLDPRT
41.0 x 6.00 x 4.00 mm

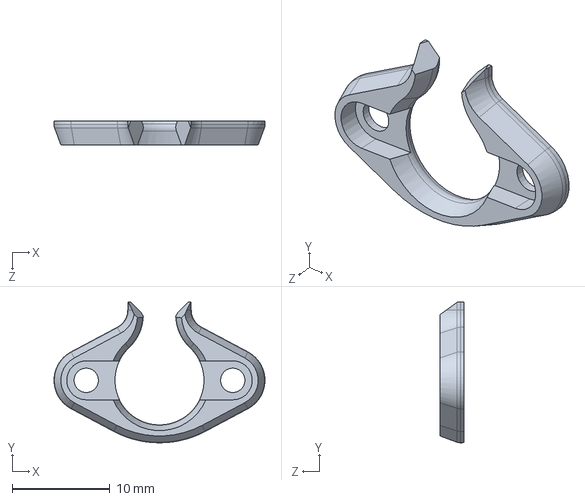
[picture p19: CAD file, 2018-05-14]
Mechanical/Chars/MagnetHolder/LB-magnetHolder-Front-RevA.SLDPRT
21.6 x 14.4 x 2.50 mm

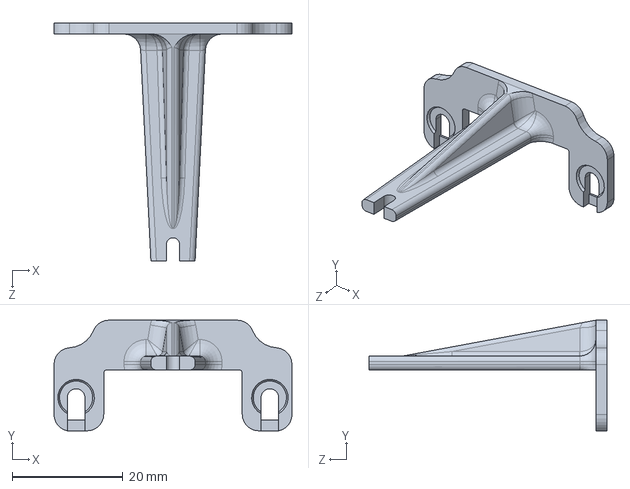
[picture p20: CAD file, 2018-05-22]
Mechanical/Word/LB-Word-charGuide.SLDPRT
43.0 x 20.0 x 43.0 mm

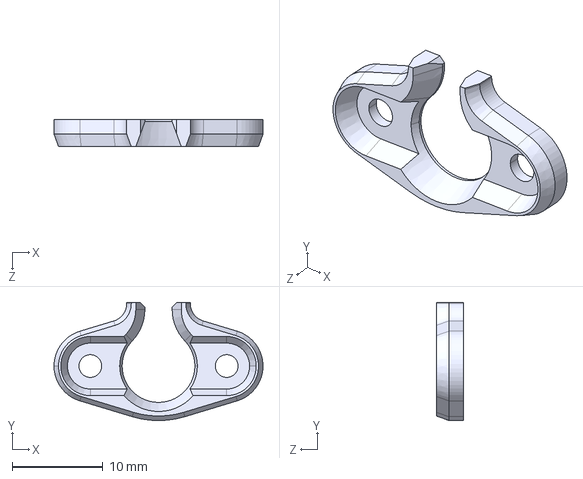
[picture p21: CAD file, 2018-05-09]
Mechanical/Chars/MagnetHolder/LB-magnetHolder-Front.STEP
23.0 x 13.0 x 3.00 mm

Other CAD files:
Mechanical/Char Display/LB-charDisp-Support.STL
Mechanical/Chars/Coil Holders/Linobyte-CoilHolderSketch.SLDPRT
Mechanical/Chars/Coil Holders/Linobyte-CoilHolderSketch.STL
Mechanical/Chars/MagnetHolder/LB-magnetHolder-Back.STL
Mechanical/Chars/MagnetHolder/LB-magnetHolder-Front-RevA.STL
Mechanical/Chars/MagnetHolder/LB-magnetHolder-Front.SLDPRT
Mechanical/Chars/MagnetHolder/LB-magnetHolder-Front.STL
Mechanical/Chars/PCB-Shape/Linobyte - PCB Shape.DWG
Mechanical/Chars/WireMagnetClamp/WireMagnetClamp.SLDPRT
Mechanical/Chars/WireMagnetClamp/WireMagnetClamp.STL
Mechanical/Word/LB-Word-charGuide-bottom.STL
Mechanical/Word/LB-Word-charGuide.STL

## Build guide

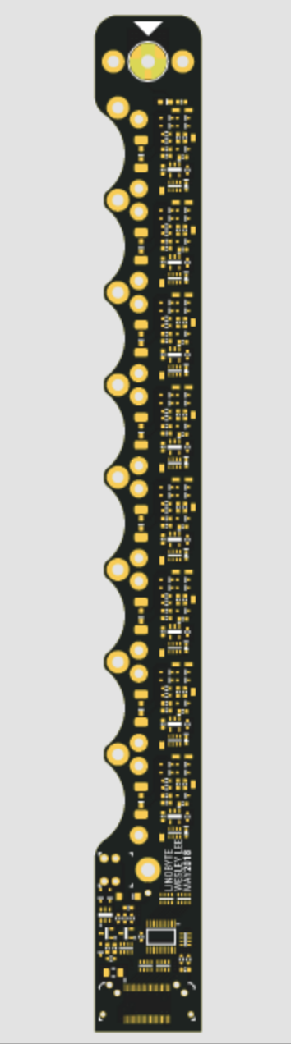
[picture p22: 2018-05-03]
Electronics/linobyte-char/Project Outputs for LinoByte - Char - Project/Fabrication/reference.png

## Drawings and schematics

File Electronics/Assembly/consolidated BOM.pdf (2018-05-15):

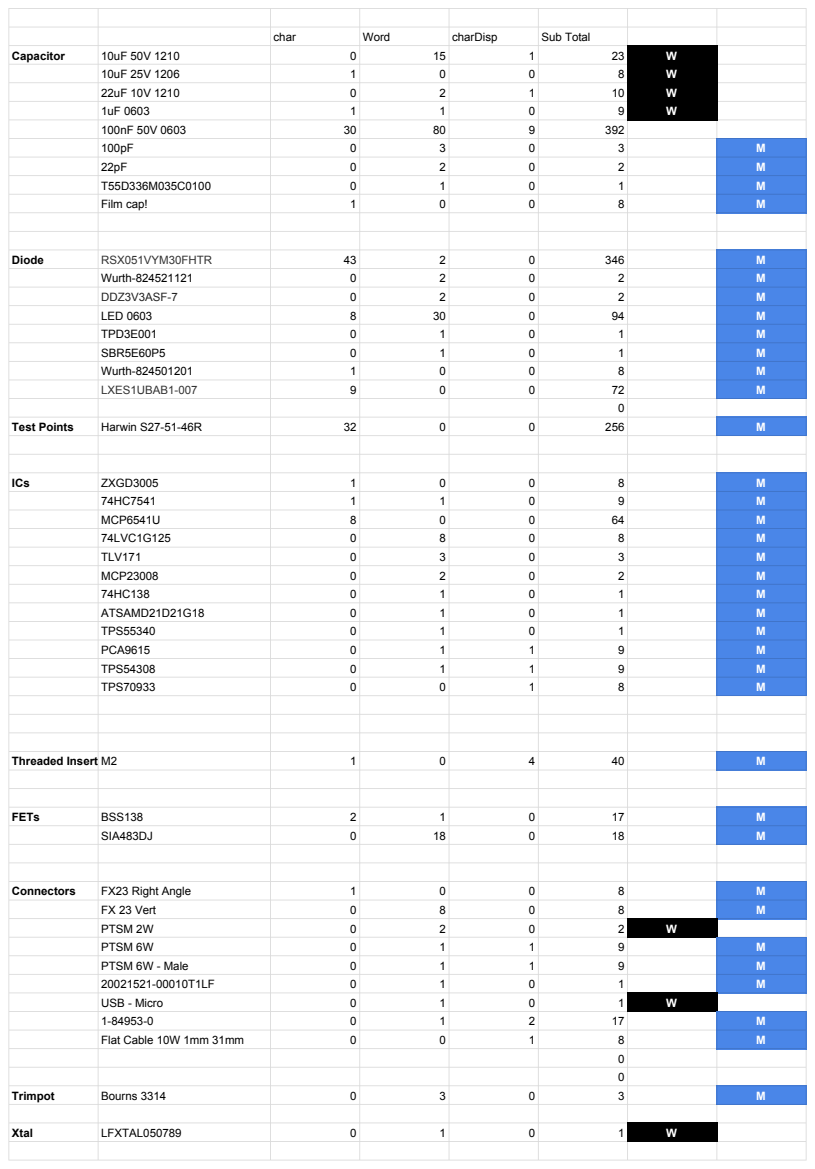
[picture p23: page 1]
char; Word; charDisp; Sub Total; Capacitor; Film cap!; Diode; RSX051VYM30FHTR; Wurth-824521121; Test Points; Harwin S27-51-46R; ICs; ZXGD3005; MCP6541U; 74LVC1G125; TLV171; MCP23008; ATSAMD21D21G18; TPS55340; PCA9615; TPS54308; TPS70933; Threaded Insert M2; FETs; BSS138; SIA483DJ; Connectors; FX23 Right Angle; FX 23 Vert; PTSM 2W; PTSM 6W; PTSM 6W - Male; USB - Micro; Flat Cable 10W 1mm 31mm; Trimpot; Bourns 3314; Xtal; LFXTAL050789

DDZ3V3ASF-7 | 0 2 | M
LED 0603 8 30 0 94 TPD3E001 0 1 0 1 SBR5E60P5 0 1 0 1 Wurth-824501201 1 0 0 8 | | M M

LXES1UBAB1-007 | 9 0 0 72 | M

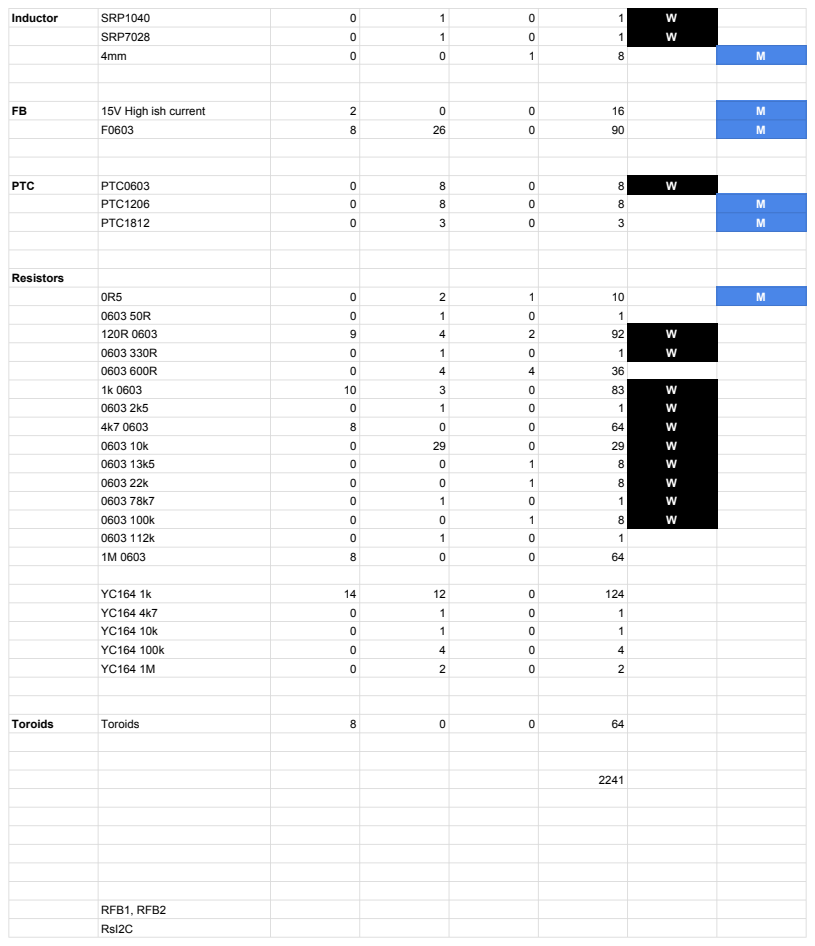
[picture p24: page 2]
Inductor; SRP1040; SRP7028; 15V High ish current; PTC; PTC0603; PTC1206; PTC1812; Resistors; Toroids; RFB1, RFB2; RsI2C

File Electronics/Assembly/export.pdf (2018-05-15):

# Char

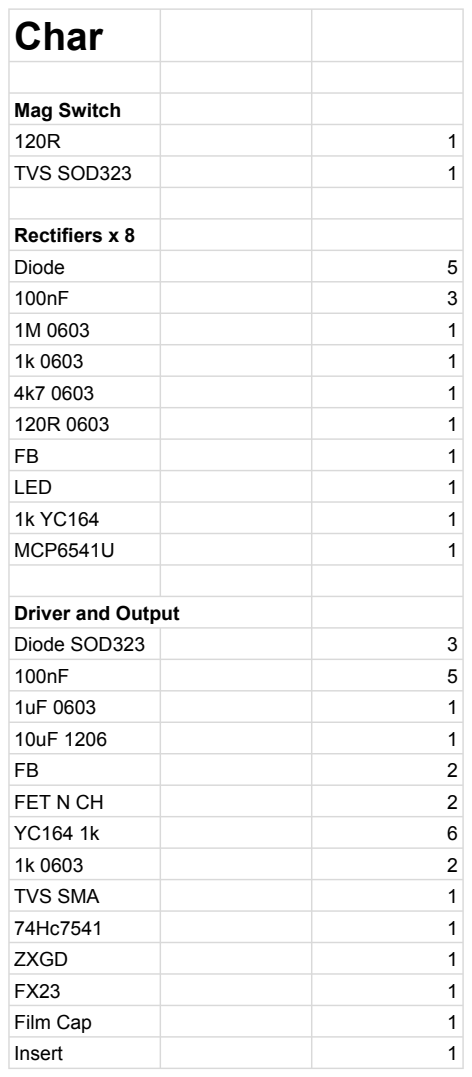
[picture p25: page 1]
Mag Switch; TVS SOD323; Rectifiers x 8; Diode; LED; MCP6541U; Driver and Output; Diode SOD323; FET N CH; TVS SMA; ZXGD; Film Cap; Insert

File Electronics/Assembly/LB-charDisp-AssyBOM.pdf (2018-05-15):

# Char Disp

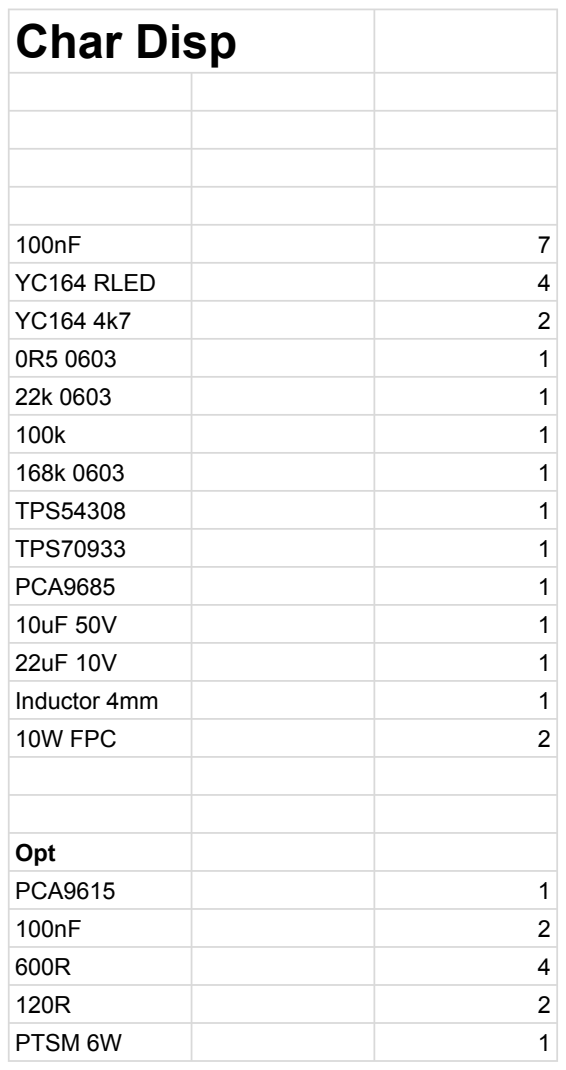
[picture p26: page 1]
YC164 RLED; TPS54308; TPS70933; PCA9685; Inductor 4mm; 10W FPC; Opt; PCA9615; PTSM 6W

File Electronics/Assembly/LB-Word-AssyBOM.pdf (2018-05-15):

# Power OR

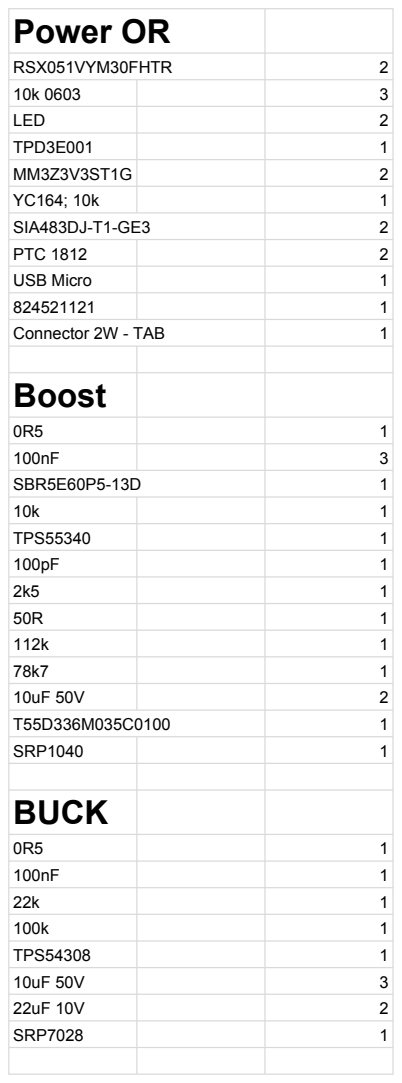
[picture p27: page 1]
RSX051VYM30FHTR; LED; TPD3E001; SIA483DJ-T1-GE3; PTC 1812; USB Micro; Connector 2W - TAB; Boost; SBR5E60P5-13D; TPS55340; SRP1040; BUCK; TPS54308; SRP7028

# OSC

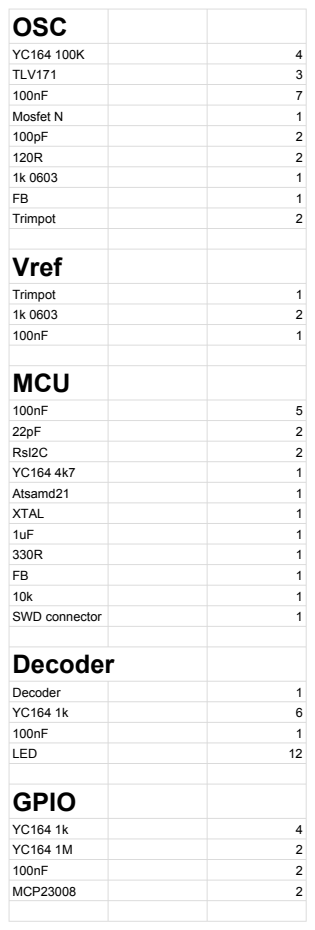
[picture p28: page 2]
TLV171; Mosfet N; Trimpot; Vref; MCU; RsI2C; Atsamd21; XTAL; SWD connector; Decoder; LED; GPIO; MCP23008

# Buffer

# I2C to Diff

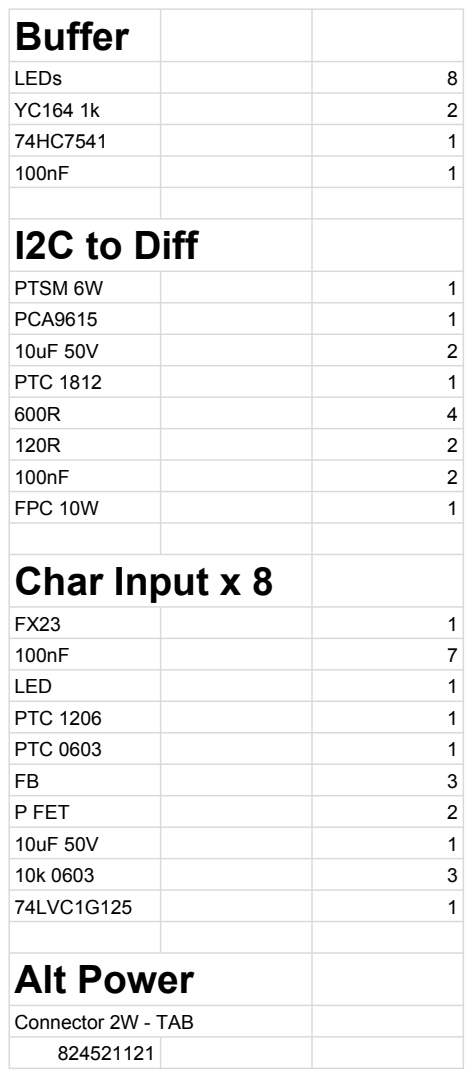
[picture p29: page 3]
LEDs; PTSM 6W; PCA9615; PTC 1812; FPC 10W; Char Input x 8; LED; PTC 1206; PTC 0603; P FET; 74LVC1G125; Alt Power; Connector 2W - TAB

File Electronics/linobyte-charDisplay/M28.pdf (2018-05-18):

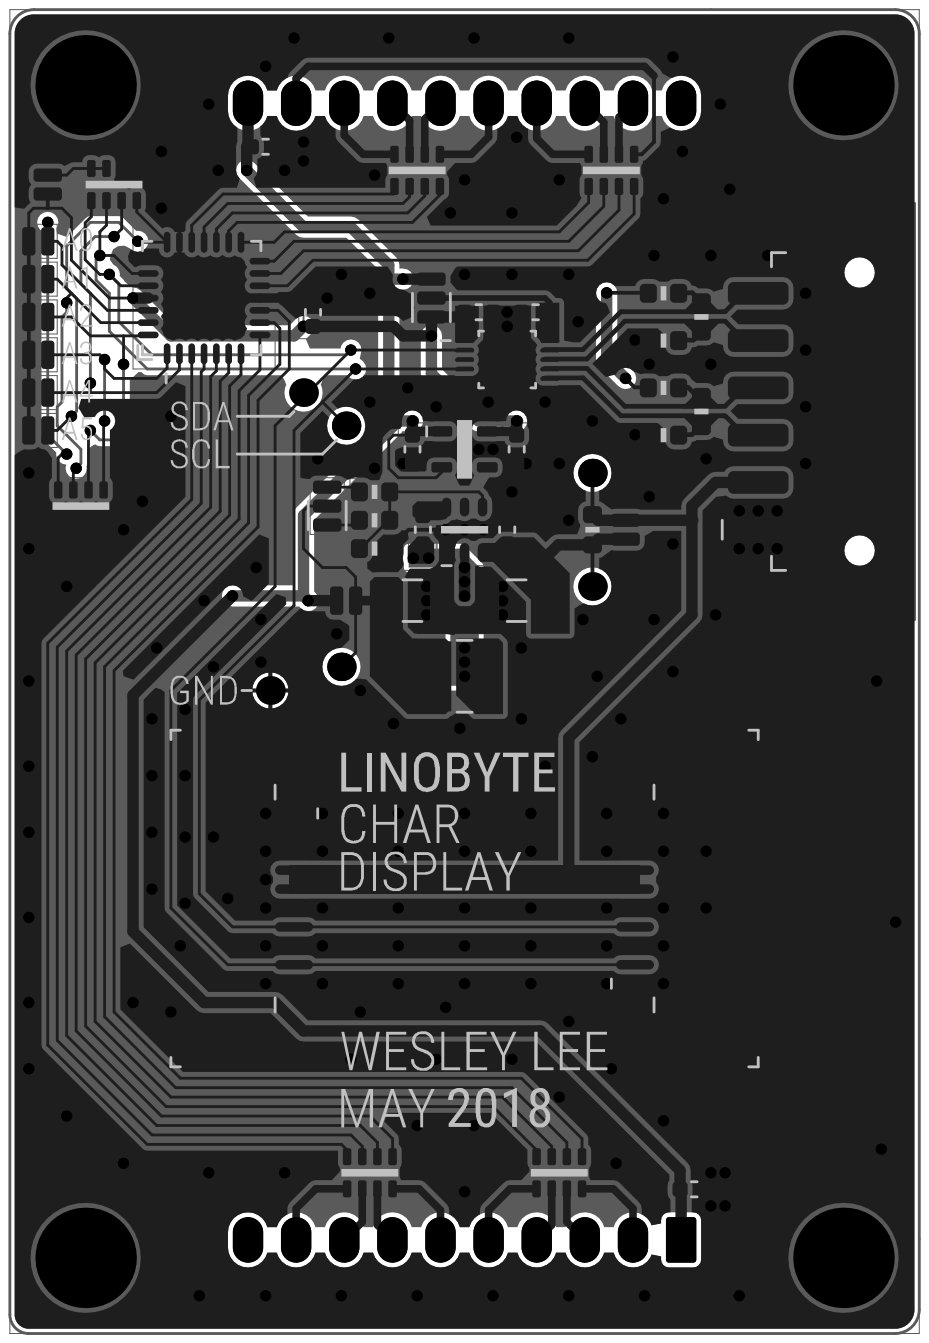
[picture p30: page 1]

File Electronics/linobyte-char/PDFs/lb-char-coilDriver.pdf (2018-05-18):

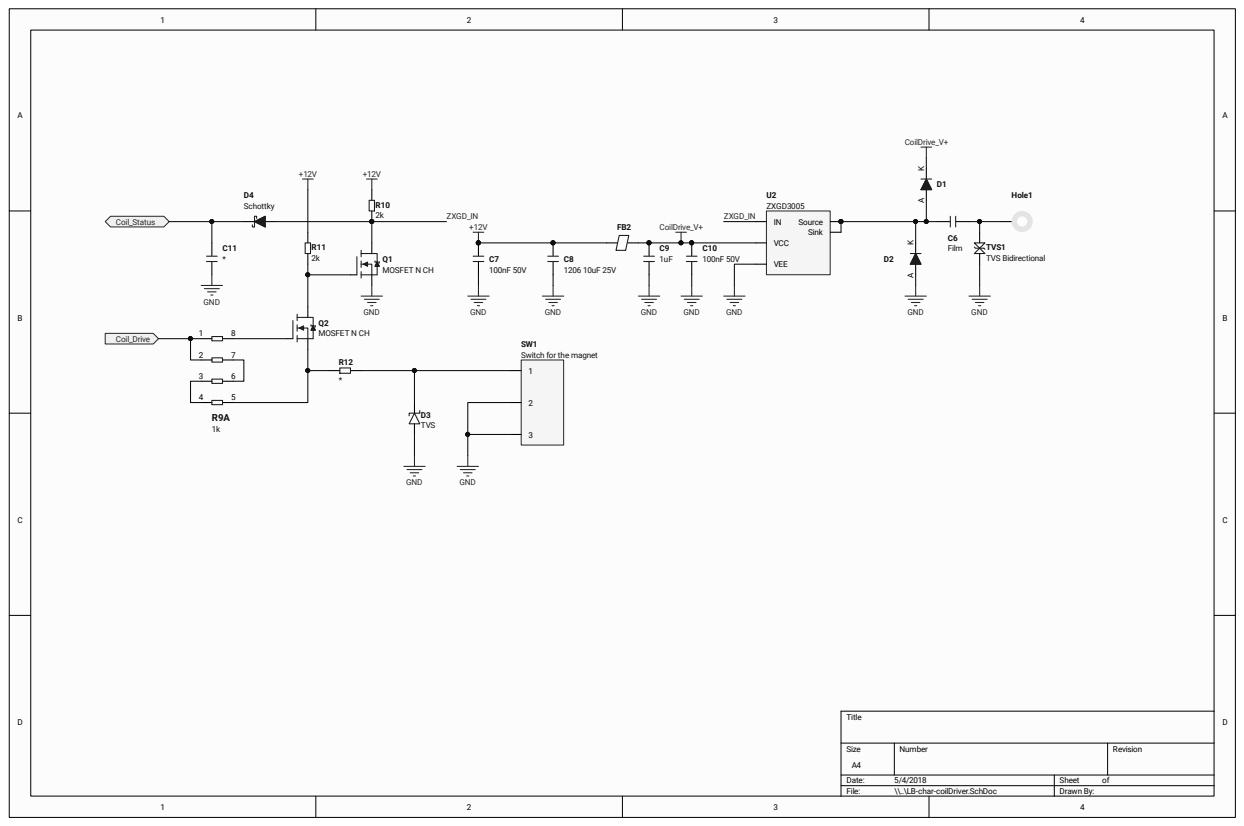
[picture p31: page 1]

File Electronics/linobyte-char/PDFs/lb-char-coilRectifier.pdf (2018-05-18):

1

2

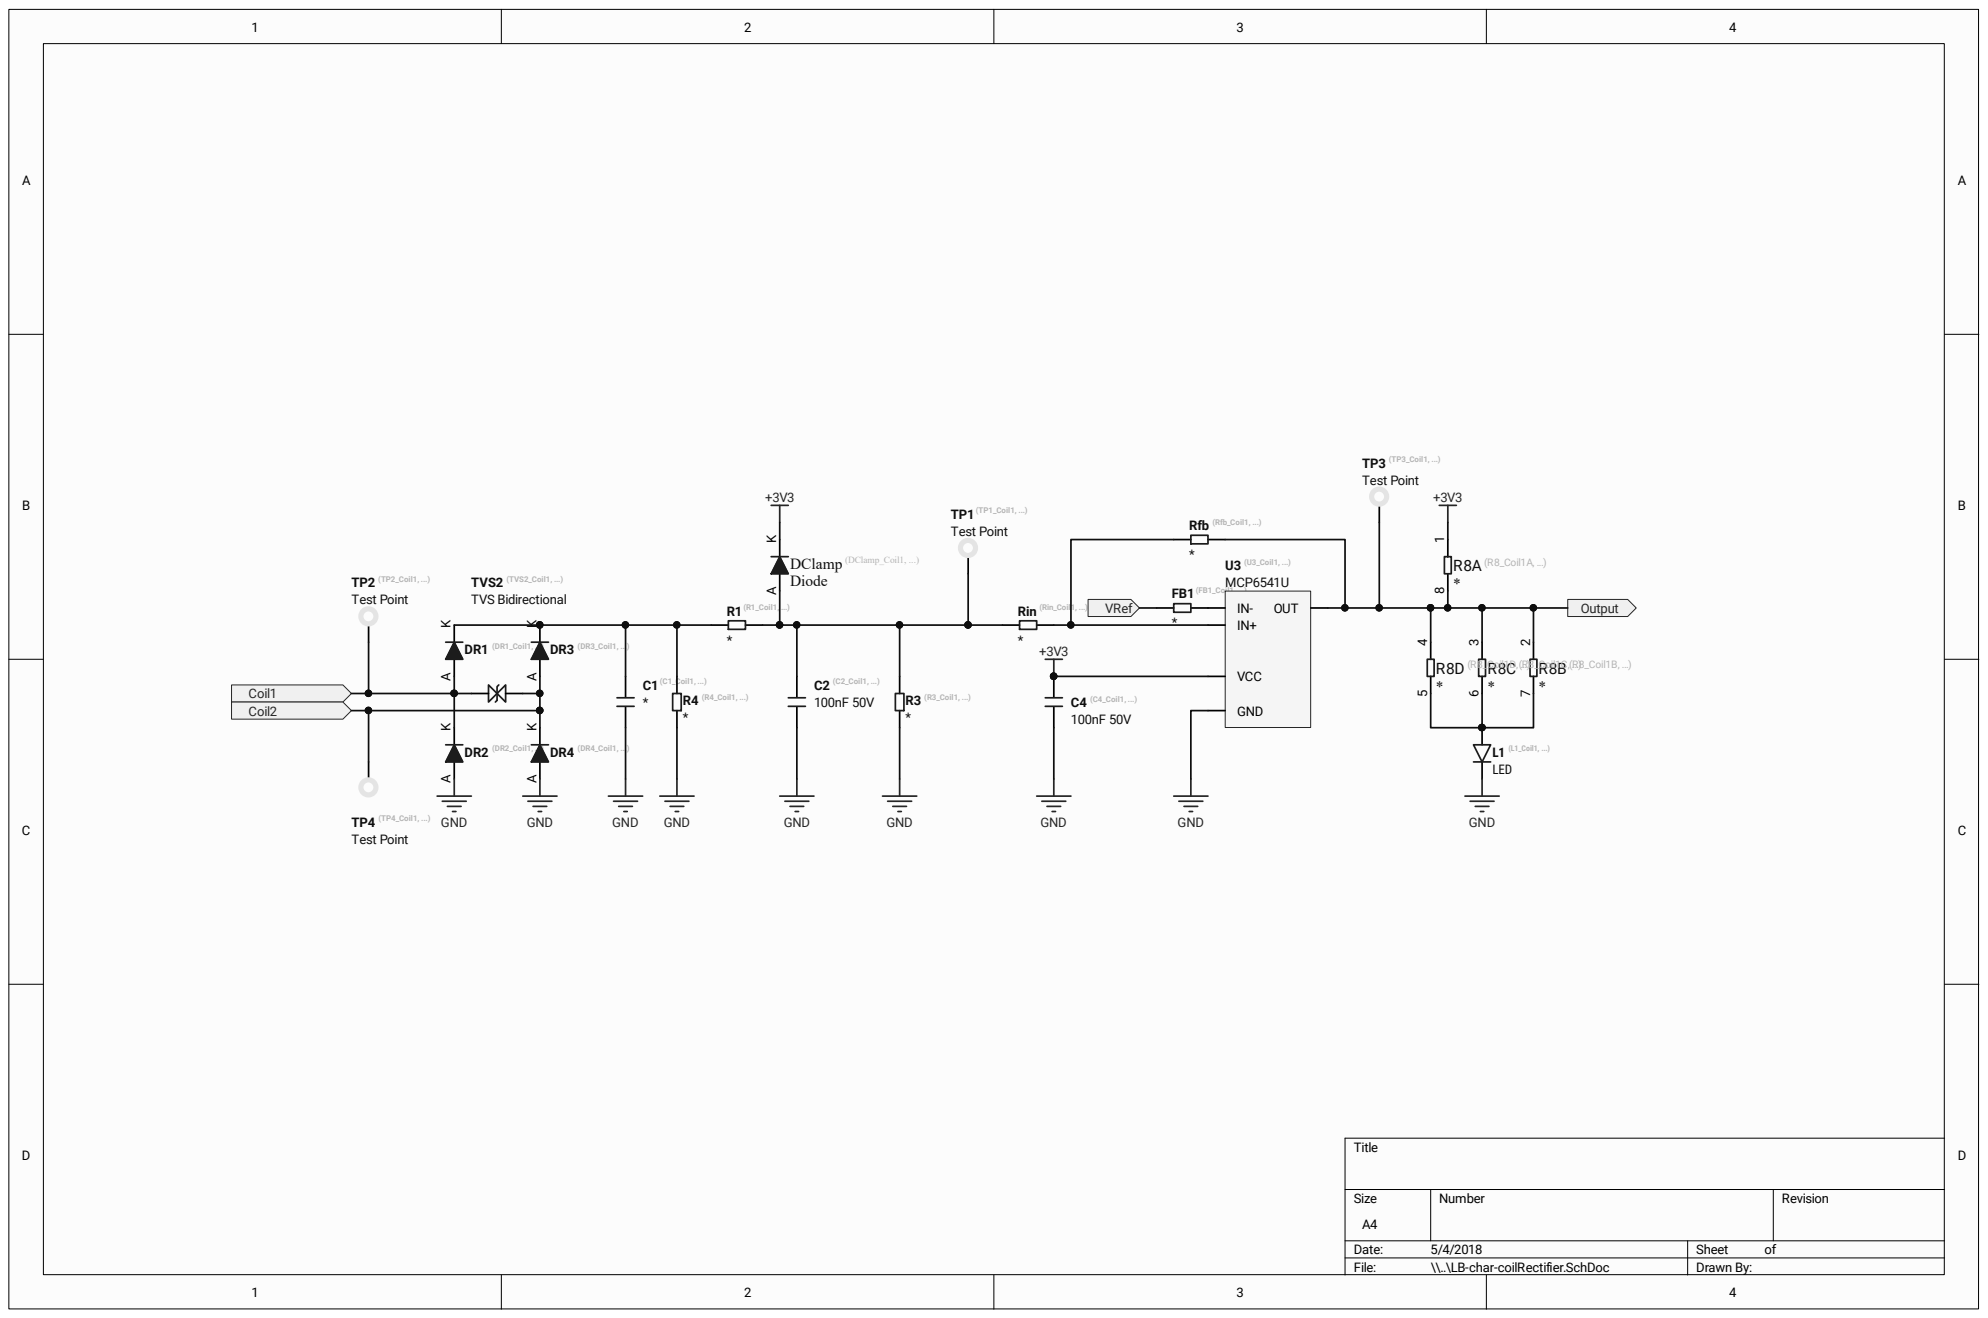
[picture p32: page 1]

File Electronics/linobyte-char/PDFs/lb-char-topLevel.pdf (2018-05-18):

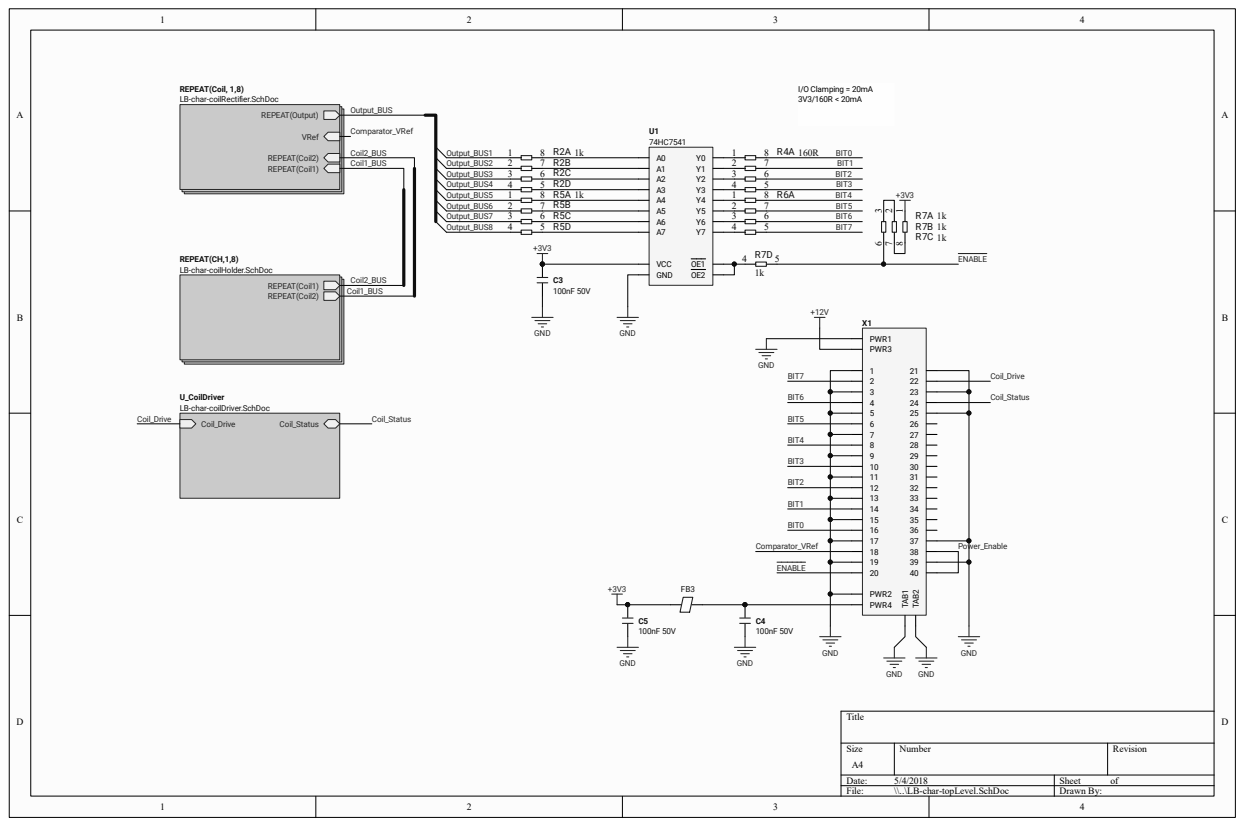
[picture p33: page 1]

REPEAT(Coil, 1,8)
LB-char-coilRectifier.SchDoc

REPEAT(CH,1,8)
LB-char-coilHolder.SchDoc

U_CoilDriver
LB-char-coilDriver.SchDoc

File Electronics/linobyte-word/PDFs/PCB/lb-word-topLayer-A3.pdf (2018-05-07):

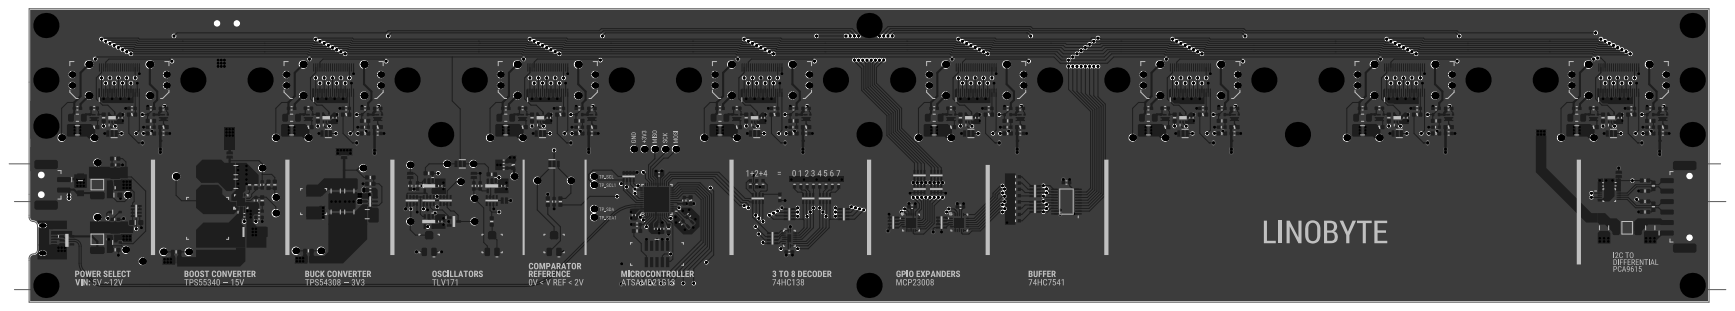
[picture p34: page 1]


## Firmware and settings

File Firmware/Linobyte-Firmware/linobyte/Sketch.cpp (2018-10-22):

#include <Arduino.h>

#include <Wire.h>
#include "wiring_private.h"
#include <Adafruit_MCP23008.h>
#include "PCA9685.h"

#include "ASCII-16Seg.h"

Adafruit_MCP23008 mcp_bits;
Adafruit_MCP23008 mcp_status;

TwoWire displayI2C(&sercom1, 11, 13);

Adafruit_PWMServoDriver charDisp[] =
{
	Adafruit_PWMServoDriver(&displayI2C, 0x60),
	Adafruit_PWMServoDriver(&displayI2C, 0x61),
	Adafruit_PWMServoDriver(&displayI2C, 0x62),
	Adafruit_PWMServoDriver(&displayI2C, 0x63),
	Adafruit_PWMServoDriver(&displayI2C, 0x64),
	Adafruit_PWMServoDriver(&displayI2C, 0x65),
	Adafruit_PWMServoDriver(&displayI2C, 0x66),
	Adafruit_PWMServoDriver(&displayI2C, 0x67)
};







//function prototypes
void enableChar(int _charToEnable);
void writeCharDisp(uint16_t _charToShow, Adafruit_PWMServoDriver& _charDisp, uint16_t _brightness);
void writeCharDisp_Off(Adafruit_PWMServoDriver& _charDisp);

EPortType port1;
EPortType port3;
EPortType port4;

uint32_t pinMask1;
uint32_t pinMask3;
uint32_t pinMask4;



void setup() {

	SerialUSB.begin(500000);
	
	mcp_bits.begin(0); // address 0
	mcp_status.begin(1); // address 1
	
	// i2c for mcp23008
	Wire.setClock(400000);
	
	// sets pins in both MCP23008 as INPUTs
	mcp_bits.write8(MCP23008_IODIR, 0b11111111);
	mcp_status.write8(MCP23008_IODIR, 0b11111111);

	//decoder
	pinMode(0, OUTPUT);
	pinMode(1, OUTPUT);
	pinMode(3, OUTPUT);
	pinMode(4, OUTPUT);
	
	//enable decoder
	digitalWrite(0,HIGH);
	
	displayI2C.begin();
	displayI2C.setClock(800000);
	
	// Assign pins 13 & 11 to SERCOM functionality
	pinPeripheral(11, PIO_SERCOM);
	pinPeripheral(13, PIO_SERCOM);


	for(int i = 0; i< 8; i++){
		charDisp[i].setPWMFreq(1000);
		writeCharDisp_Off(charDisp[i]);
		//writeCharDisp(0, charDisp[i], 4095);
	}
	
	
	port1 = g_APinDescription[1].ulPort;
	uint32_t pin1 = g_APinDescription[1].ulPin;
	pinMask1 = (1ul << pin1);
	
	port3 = g_APinDescription[3].ulPort;
	uint32_t pin3 = g_APinDescription[3].ulPin;
	pinMask3 = (1ul << pin3);
	
	port4 = g_APinDescription[4].ulPort;
	uint32_t pin4 = g_APinDescription[4].ulPin;
	pinMask4 = (1ul << pin4);
}


int charBeingChecked = 0;

double delayBetweenChars = 1000000.0f;
int charsLooped = 1;


unsigned long lastStep = 0;

int mcpVal = 0;

int delayState = 0;

void loop() {
	


	
	// 	SerialUSB.print(charBeingChecked);
	// 	SerialUSB.print(" being checked...");
	// 	SerialUSB.print("");
	//
	//
	// 	//delayMicroseconds(15000);
	//
	// 	SerialUSB.print(mcp_status.digitalRead(7-charBeingChecked));
	//
	// 	//	if(mcp_status.digitalRead(7-charBeingChecked)){
	//
	// 	SerialUSB.print("\tAttached: ");
	// 	SerialUSB.write(mcp_bits.readGPIO());
	// 	SerialUSB.print(SixteenSegmentASCII[mcp_bits.readGPIO()-32],BIN);
	//
	//
	// 	/*
	// 	// Array starts with "space", ASCII no 32, hence "-32"
	// 	SixteenSegmentASCII[mcp_bits.readGPIO()-32]
	// 	*/
	//

	// 	SerialUSB.println();
	// 	}
	// 	else{
	// 		SerialUSB.print("\tNot Attached...\r\n");
	// 	}
	

	if(micros() - lastStep > delayBetweenChars){
		lastStep = micros();
		enableChar(charBeingChecked);
		if(delayBetweenChars > 2000){
			delay(2);
		}
		else{
			//
		}

		// reads the char
		mcpVal = mcp_bits.readGPIO() - 32;

		if(delayState != 2){
			if (mcpVal > 32 && mcpVal < 59){
				writeCharDisp(mcpVal, charDisp[charBeingChecked], 4095);
			}
			else{
				writeCharDisp(999,charDisp[charBeingChecked],4095);
			}
			
			
			if(charBeingChecked !=0)
			writeCharDisp_Off(charDisp[charBeingChecked-1]);
			else
			writeCharDisp_Off(charDisp[7]);
		}
		
		
		
		if(delayState == 0){
			delayBetweenChars = delayBetweenChars/1.02f;
			if (delayBetweenChars < 1500) delayState++;
		}
		else if(delayState == 1){
			delayBetweenChars = 0;
			if(charsLooped > 800) delayState++;
		}
		else if(delayState == 2){
			//delay(10000);
			if (mcpVal > 32 && mcpVal < 59){
				//writeCharDisp(mcpVal, charDisp[charBeingChecked], 1000);
				writeCharDisp(mcpVal, charDisp[charBeingChecked], 4095);
			}
			else{
				writeCharDisp(999,charDisp[charBeingChecked],1000);
			}
			if(charsLooped > 3000) {
				for(int i = 0; i < 8; i++){
					writeCharDisp_Off(charDisp[i]);
					
				}
				delayState = 0;
				charsLooped = 1;
				delayBetweenChars = 1000000.0f;
			}
		}

		charBeingChecked++;
		if(charBeingChecked == 8) {
			charBeingChecked = 0;
			charsLooped++;

		}	
	}
	
}



void enableChar(int _charToEnable){
	
	switch (_charToEnable)
	{
		case 0:
		PORT->Group[port1].OUTCLR.reg = pinMask1; // A0
		PORT->Group[port3].OUTCLR.reg = pinMask3; // A1
		PORT->Group[port4].OUTCLR.reg = pinMask4; // A2
		break;
		case 1:
		PORT->Group[port1].OUTSET.reg = pinMask1;
		//PORT->Group[port3].OUTCLR.reg = pinMask3;
		//PORT->Group[port4].OUTCLR.reg = pinMask4;
		break;
		case 2:
		PORT->Group[port1].OUTCLR.reg = pinMask1;
		PORT->Group[port3].OUTSET.reg = pinMask3;
		//PORT->Group[port4].OUTCLR.reg = pinMask4;
		break;
		case 3:
		
		PORT->Group[port1].OUTSET.reg = pinMask1;
		PORT->Group[port3].OUTSET.reg = pinMask3;
		//PORT->Group[port4].OUTCLR.reg = pinMask4;
		break;
		case 4:
		
		PORT->Group[port1].OUTCLR.reg = pinMask1;
		PORT->Group[port3].OUTCLR.reg = pinMask3;
		PORT->Group[port4].OUTSET.reg = pinMask4;
		break;
		case 5:
		
		PORT->Group[port1].OUTSET.reg = pinMask1;
		//PORT->Group[port3].OUTCLR.reg = pinMask3;
		//PORT->Group[port4].OUTSET.reg = pinMask4;
		break;
		case 6:
		PORT->Group[port1].OUTCLR.reg = pinMask1;
		PORT->Group[port3].OUTSET.reg = pinMask3;
		//PORT->Group[port4].OUTSET.reg = pinMask4;
		break;
		case 7:
		
		PORT->Group[port1].OUTSET.reg = pinMask1;
		//PORT->Group[port3].OUTSET.reg = pinMask3;
		//PORT->Group[port4].OUTSET.reg = pinMask4;
		break;
	}
	
}



/*
LED0	C	3
LED1	L	12
LED2	D2	4
LED3	M	13
LED4	N	14
LED5	D1	5
LED6	E	6
LED7	P	15

LED8	K	11
LED9	F	7
LED10	G	8
LED11	A1	0
LED12	H	9
LED13	J	10
LED14	A2	1
LED15	B	2
*/


//	U	T	S	R	P	N	M	K	H	G	F	E	 D	C	B	A
//	P	N	M	L	K	J	H	G	F	E	D1	D2	C	B	A2	A1
//	15	14	13	12	11	10	9	8	7	6	5	4	3	2	1	0

// mapping from ascii library to hardware layout, i.e.: 0b0000000000000001 == LED 11
const int bitToPCA9685Map [16] = {11,14,15,0,2,5,6,9,10,12,13,8,1,3,4,7};

void writeCharDisp(uint16_t _charToShow, Adafruit_PWMServoDriver& _charDisp, uint16_t _brightness){

	for(int i = 0; i < 16; i++){
		if((1 << i) & SixteenSegmentASCII[_charToShow]){
			_charDisp.setPin(bitToPCA9685Map[i],_brightness,true);
		}
		else{
			_charDisp.setPin(bitToPCA9685Map[i],0,true);
		}
	}

}


void writeCharDisp_Off(Adafruit_PWMServoDriver& _charDisp){
	_charDisp.setAllOff();
	
}

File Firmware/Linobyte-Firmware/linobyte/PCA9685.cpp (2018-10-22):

/***************************************************
This is a library for our Adafruit 16-channel PWM & Servo driver
Pick one up today in the adafruit shop!
------> http://www.adafruit.com/products/815
These displays use I2C to communicate, 2 pins are required to
interface.
Adafruit invests time and resources providing this open source code,
please support Adafruit and open-source hardware by purchasing
products from Adafruit!
Written by Limor Fried/Ladyada for Adafruit Industries.
BSD license, all text above must be included in any redistribution
****************************************************/

#include "PCA9685.h"
#include <Wire.h>

// Set to true to print some debug messages, or false to disable them.
//#define ENABLE_DEBUG_OUTPUT


/**************************************************************************/
/*!
@brief  Instantiates a new PCA9685 PWM driver chip with the I2C address on the Wire interface. On Due we use Wire1 since its the interface on the 'default' I2C pins.
@param  addr The 7-bit I2C address to locate this chip, default is 0x40
*/
/**************************************************************************/
Adafruit_PWMServoDriver::Adafruit_PWMServoDriver(uint8_t addr) {
	_i2caddr = addr;

	#if defined(ARDUINO_SAM_DUE)
	_i2c = &Wire1;
	#else
	_i2c = &Wire;
	#endif
}

/**************************************************************************/
/*!
@brief  Instantiates a new PCA9685 PWM driver chip with the I2C address on a TwoWire interface
@param  i2c  A pointer to a 'Wire' compatible object that we'll use to communicate with
@param  addr The 7-bit I2C address to locate this chip, default is 0x40
*/
/**************************************************************************/
Adafruit_PWMServoDriver::Adafruit_PWMServoDriver(TwoWire *i2c, uint8_t addr) {
	_i2c = i2c;
	_i2caddr = addr;
}

/**************************************************************************/
/*!
@brief  Setups the I2C interface and hardware
*/
/**************************************************************************/
void Adafruit_PWMServoDriver::begin(void) {
	_i2c->begin();
	
	reset();
	// set a default frequency
	setPWMFreq(1000);
}


/**************************************************************************/
/*!
@brief  Sends a reset command to the PCA9685 chip over I2C
*/
/**************************************************************************/
void Adafruit_PWMServoDriver::reset(void) {
	write8(PCA9685_MODE1, 0x80);
	delay(10);
	
	delay(5);
	uint8_t oldmode = read8(PCA9685_MODE2); // read current Mode2 register
	uint8_t newmode = (oldmode&0x7F) & ~(0x1<<2);
	write8(PCA9685_MODE2, newmode); // write totem pole configuration
	newmode = (oldmode&0x7F) & ~(0x1<<4);
	write8(PCA9685_MODE2, newmode);
}

/**************************************************************************/
/*!
@brief  Sets the PWM frequency for the entire chip, up to ~1.6 KHz
@param  freq Floating point frequency that we will attempt to match
*/
/**************************************************************************/
void Adafruit_PWMServoDriver::setPWMFreq(float freq) {
	reset();
	#ifdef ENABLE_DEBUG_OUTPUT
	Serial.print("Attempting to set freq ");
	Serial.println(freq);
	#endif

	freq *= 0.9;  // Correct for overshoot in the frequency setting (see issue #11).
	float prescaleval = 25000000;
	prescaleval /= 4096;
	prescaleval /= freq;
	prescaleval -= 1;

	#ifdef ENABLE_DEBUG_OUTPUT
	Serial.print("Estimated pre-scale: "); Serial.println(prescaleval);
	#endif

	uint8_t prescale = floor(prescaleval + 0.5);
	#ifdef ENABLE_DEBUG_OUTPUT
	Serial.print("Final pre-scale: "); Serial.println(prescale);
	#endif
	
	
	
	uint8_t oldmode = read8(PCA9685_MODE1);
	uint8_t newmode = (oldmode&0x7F) | 0x10; // sleep
	write8(PCA9685_MODE1, newmode); // go to sleep
	write8(PCA9685_PRESCALE, prescale); // set the prescaler
	write8(PCA9685_MODE1, oldmode);
	delay(5);
	write8(PCA9685_MODE1, oldmode | 0xa0);  //  This sets the MODE1 register to turn on auto increment.

	delay(5);
	oldmode = read8(PCA9685_MODE2); // read current Mode2 register
	newmode = (oldmode&0x7F) & ~(0x1<<2);
	write8(PCA9685_MODE2, newmode); // write totem pole configuration
	newmode = (oldmode&0x7F) & ~(0x1<<4);
	write8(PCA9685_MODE2, newmode);

	#ifdef ENABLE_DEBUG_OUTPUT
	Serial.print("Mode now 0x"); Serial.println(read8(PCA9685_MODE1), HEX);
	#endif
}

/**************************************************************************/
/*!
@brief  Sets the PWM output of one of the PCA9685 pins
@param  num One of the PWM output pins, from 0 to 15
@param  on At what point in the 4096-part cycle to turn the PWM output ON
@param  off At what point in the 4096-part cycle to turn the PWM output OFF
*/
/**************************************************************************/
void Adafruit_PWMServoDriver::setPWM(uint8_t num, uint16_t on, uint16_t off) {
	#ifdef ENABLE_DEBUG_OUTPUT
	Serial.print("Setting PWM "); Serial.print(num); Serial.print(": "); Serial.print(on); Serial.print("->"); Serial.println(off);
	#endif

	_i2c->beginTransmission(_i2caddr);
	_i2c->write(LED0_ON_L+4*num);
	_i2c->write(on);
	_i2c->write(on>>8);
	_i2c->write(off);
	_i2c->write(off>>8);
	_i2c->endTransmission();
}




void Adafruit_PWMServoDriver::setAllOff(){

	_i2c->beginTransmission(_i2caddr);
	_i2c->write(0xFA);
	_i2c->write(0b11111111);
	_i2c->write(0b11111111);
	_i2c->write(0b00000000);
	_i2c->write(0b00000000);
	_i2c->endTransmission();

}




/**************************************************************************/
/*!
@brief  Helper to set pin PWM output. Sets pin without having to deal with on/off tick placement and properly handles a zero value as completely off and 4095 as completely on.  Optional invert parameter supports inverting the pulse for sinking to ground.
@param  num One of the PWM output pins, from 0 to 15
@param  val The number of ticks out of 4096 to be active, should be a value from 0 to 4095 inclusive.
@param  invert If true, inverts the output, defaults to 'false'
*/
/**************************************************************************/
void Adafruit_PWMServoDriver::setPin(uint8_t num, uint16_t val, bool invert)
{
	// Clamp value between 0 and 4095 inclusive.
	val = min(val, (uint16_t)4095);
	if (invert) {
		if (val == 0) {
			// Special value for signal fully on.
			setPWM(num, 4096, 0);
		}
		else if (val == 4095) {
			// Special value for signal fully off.
			setPWM(num, 0, 4096);
		}
		else {
			setPWM(num, 0, 4095-val);
		}
	}
	else {
		if (val == 4095) {
			// Special value for signal fully on.
			setPWM(num, 4096, 0);
		}
		else if (val == 0) {
			// Special value for signal fully off.
			setPWM(num, 0, 4096);
		}
		else {
			setPWM(num, 0, val);
		}
	}
}

/*******************************************************************************************/
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

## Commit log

2018-04-01 PCB for Char module started
    [Buffer.SchDoc, Coil.SchDoc, Coils.SchDoc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]
2018-04-01 PCB for word started
    [Decoder.SchDoc, Linobyte - word.PrjPCB]
2018-04-01 BOM corrected
2018-04-02 Rectifiers roughly laid out, connector added
    [Buffer.SchDoc, Coil.SchDoc, LinoByte - Char.PcbDoc]
2018-04-02 Decoder added back into project
    [Linobyte - word.PrjPCB]
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2018-04-08 Comparator added to coil rooms, FET driving LED removed.
    [Buffer.SchDoc, Coil.SchDoc, LinoByte - Char.PcbDoc]
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2018-04-08 Signals from coil rooms and schmitt trigger routed
    [Coil.SchDoc, LinoByte - Char.PcbDoc]
2018-04-08 3D Models for Coil / CoilHolders started
    [Linobyte-CoilHolderSketch.SLDPRT, Linobyte-CoilHolderSketch.STEP]
2018-04-09 Coil Holders added to PCB and laid out, rooms organized in new pitch of 20mm
    [Buffer.SchDoc, Coil.SchDoc, CoilHolder.SchDoc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]
2018-04-09 Sketch of coil holder updated
    [Linobyte-CoilHolderSketch.SLDPRT, Linobyte-CoilHolderSketch.STEP]
2018-04-12 Visualization of overall system created
    [Buffer.SchDoc, Coil.SchDoc, CoilDriver.SchDoc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]
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2018-04-17 Driver and connectors for drive wire implemented
    [Buffer.SchDoc, Coil.SchDoc, CoilDriver.SchDoc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]
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2018-04-18 PCB outline defined
    [CoilDriver.SchDoc, LinoByte - Char.PcbDoc]
2018-04-18 PCB outline files
    [Linobyte - PCB Shape.DWG, Linobyte - PCB Shape.SLDPRT]
2018-04-18 PCB cut made smaller to acommodate M2.5 screws between coils
    [Linobyte - PCB Shape.DWG, Linobyte - PCB Shape.SLDPRT]
2018-04-19 Magnetic switch done, Drive disable done, mounting holes added, PCB outline done, etc
    [Buffer.SchDoc, Coil.SchDoc, CoilDriver.SchDoc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]
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2018-04-20 Sch files renamed: LB-char-___
    [CoilDriver.SchDoc, LB-char-coilDriver.SchDoc, LB-char-coilHolder.SchDoc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]
2018-04-20 Files with old names removed
    [Buffer.SchDoc, Coil.SchDoc, CoilDriver.SchDoc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]
2018-04-25 Open drain comparator replaced with push-pull, LED changed active low to active high.
    [LB-char-coilRectifier.SchDoc, LB-char-topLevel.SchDoc, LinoByte - Char.PcbDoc]
2018-04-25 Main board started
    [LB-word-charInput.SchDoc, LB-word-decoder.SchDoc, LB-word-topLevel.SchDoc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]
2018-04-25 Buffer for Char bits bus created and implemented on top level sheet
    [LB-word-charBuffer.SchDoc, LB-word-charInput.SchDoc, LB-word-charsBuffer.SchDoc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]
2018-04-29 Major blocks delineated, start PCB
    [LB-word-MCU.SchDoc, LB-word-PCB.PcbDoc, LB-word-PSU-24V.SchDoc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]
2018-04-29 Files cleanup
    [Decoder.SchDoc, LB-word-charBuffer.SchDoc]
2018-04-29 Pull Down of FET on coil driver moved from ground to Source
    [LB-char-coilDriver.SchDoc, LB-char-coilRectifier.SchDoc, LB-char-topLevel.SchDoc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]
2018-05-01 Char Input positions defined
    [LB-word-MCU.SchDoc, LB-word-PSU-24V.SchDoc, LB-word-PSU-3V.SchDoc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]
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2018-05-03 Char sent to mfg.
    [LB-char-coilDriver.SchDoc, LB-char-coilHolder.SchDoc, LB-char-coilRectifier.SchDoc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]
2018-05-04 Update on FX23 Solder Mask - 0.2mm slivers removed
    [LinoByte - Char.PcbDoc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]
2018-05-06 Char Display PCB and Sch started
    [lb-charDisp-SMPS5V.SchDoc, lb-charDisp-topLevel.SchDoc, lb-charDisplay-PCB1.PcbDoc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]
2018-05-06 I2C to diff I2C
    [LB-word-diffI2C.SchDoc]
2018-05-07 Version sent to manufacturing
    [lb-charDisp-topLevel.SchDoc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]
2018-05-07 Version sent to manufacture
    [LB-word-MCU.SchDoc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]
2018-05-08 Solder mask sliver adjusted
    [lb-charDisp-SMPS5V.SchDoc, lb-charDisp-topLevel.SchDoc, lb-charDisplay-PCB1.PcbDoc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]
2018-05-08 Solder mask sliver updated
    [LB-word-MCU.SchDoc, LB-word-PSU-24V.SchDoc, LB-word-PSU-3V.SchDoc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]
2018-05-09 Wire and magnet connector prototype
    [WireMagnetClamp.SLDPRT, WireMagnetClamp.STL]
2018-05-09 Holder of fixed magnet in the back of char
    [Back.SLDPRT]
2018-05-09 Updated holes for M2
    [Back.SLDPRT, LB-magnetHolder-Back.SLDPRT, LB-magnetHolder-Back.STL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]
2018-05-09 PCB Shape folder organized
    [Linobyte - PCB Shape.DWG, Linobyte - PCB Shape.SLDPRT]
2018-05-09 STP file for Altium
    [WireMagnetClamp.STEP]
2018-05-09 STL ready for print
    [WireMagnetClamp.SLDPRT, WireMagnetClamp.STL]
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2018-05-14 Rev A printed, to be tested
    [LB-magnetHolder-Back.SLDPRT, LB-magnetHolder-Back.STL, LB-magnetHolder-Front-RevA.SLDPRT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]
2018-05-15 Removed block for M2.5 screw on PCB
    [Linobyte-CoilHolderSketch.SLDPRT, Linobyte-CoilHolderSketch.STEP, Linobyte-CoilHolderSketch.STL]
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2018-05-18 Resistor values updated to reflect build
    [LB-char-coilDriver.SchDoc, LB-char-coilRectifier.SchDoc, LB-char-topLevel.SchDoc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]
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2018-05-20 Firmware for linobyte started
    [arduino_zero.cfg]
2018-05-20 MCP23008 and 74HC138 tested
    [arduino_zero.cfg]
2018-05-20 Notes added - TLV171 inputs on left oscillator needs to be corrected
    [LB-word-oscillator.SchDoc]
2018-05-20 Zener added to LED to reject leackage current. (Otherwise it lights up faintly)
    [LB-word-powerOR-RevA.SchDoc]
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2018-05-22 Back magnet holders printed
    [LB-magnetHolder-Back.SLDPRT, LB-magnetHolder-Back.STL]
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2018-06-01 Set screw changed from M5 to M4
    [LB-charDisp-Support.SLDPRT]
2018-06-01 Set screws changed from M5 to M4 - printed
    [LB-charDisp-Support.SLDPRT, LB-charDisp-Support.STL]
2018-06-02 Tubeb diam changed to 4.2mm holes offset 0.5mm vertically
    [LB-charDisp-Support.SLDPRT, LB-charDisp-Support.STL]
2018-06-22 Threaded plate to hold charGuide
    [LB-Word-charGuide-bottom.SLDPRT, LB-Word-charGuide-bottom.STL]
